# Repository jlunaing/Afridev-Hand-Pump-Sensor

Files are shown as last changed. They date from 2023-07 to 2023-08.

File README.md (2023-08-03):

# Monitoring System for the Afridev Hand Pump

## Overview

[Source code](src), [circuit schematic and board files](pcb), and [**technical report**](docs) of a proof-of-concept electronic system to monitor the status of the Afridev model of hand pumps.

<p align="middle">
   
</p>

<p align="middle">
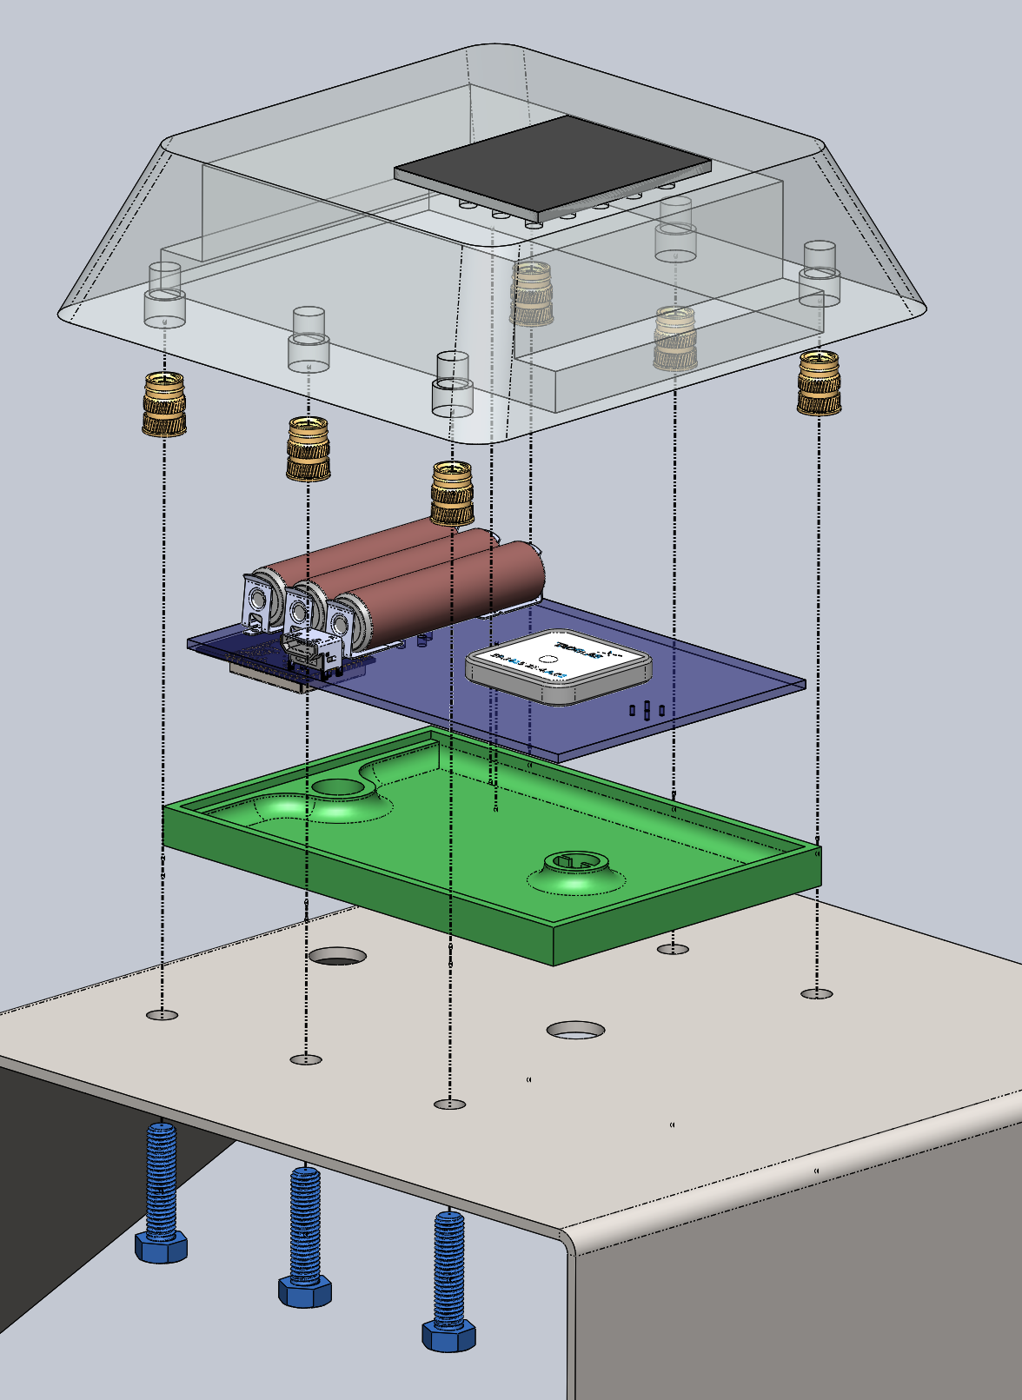
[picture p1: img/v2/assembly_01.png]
   
</p>

<p align="middle">
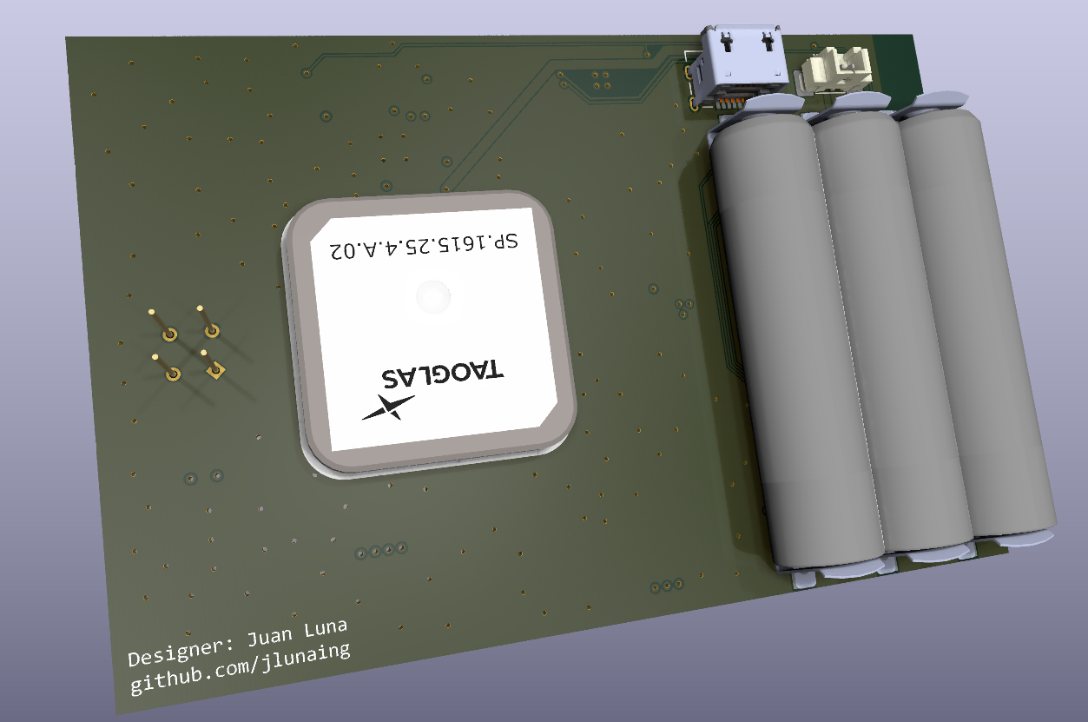
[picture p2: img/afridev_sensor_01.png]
Figure 3A
  
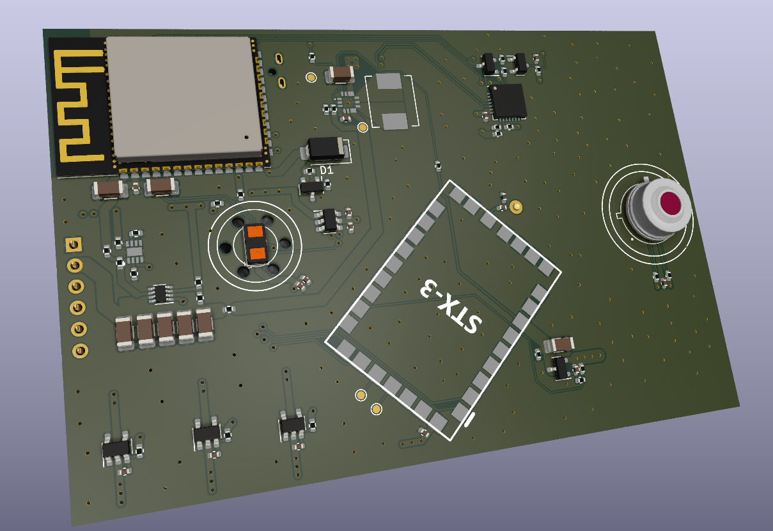
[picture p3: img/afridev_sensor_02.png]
Figure 3B
   
</p>

## Introduction

Different companies, non-profit organizations, and NGOs have implemented water projects in several regions of Africa. One of the most common projects are hand pumps for water wells. A challenge that is presented once these projects are concluded and used by the local residents are that there is no regular maintenance of these hand pumps due to communication difficulties with the local communities. For instance, in most of the Democratic Republic of the Congo (DRC), the lack of cellular signal and internet connection makes it more difficult for repair teams to know when the hand pumps need repair or maintenance. 

The objective of this project is to propose a system that can reduce the time between pump failure and repair by developing a reliable failure detection measuring system that will inform a user when a pump need attention from a repair team. The system will collect data on pump usage and water flow rate estimation to be accessed remotely.

The reduction in hand pump repair time would increase the consistency of well water available to people in the remote areas like the DRC.

## Technical Background

Currently, there are no commercially available options for well pump sensors with the capabilities to detect pump function, monitor water flow rate, and transmit data internationally. However, open-source systems of a similar nature have been developed by other organizations. A notable one is [Charity: Water](https://www.charitywater.org/), a non-profit serving several developing countries through community water projects and sanitation efforts. Their [sensors](https://www.charitywater.org/our-work/sensors)&mdash;which can be retrofitted onto the Afridev, Tapstand, and India Mark II hand pump models&mdash;are able to collect data on the quantity of water being pumped from a well. The gathered data is transmitted to the cloud weekly via cellular networks, where it is stored, processed, and made viewable by an application running on Amazon Web Services (AWS). The Afridev model appears to have been developed from 2016 to 2020 by Intelligent Product Solutions (IPS), while the India Mark II sensor was developed in 2021 by TwistThink over the course of at least a year.

Extensive documentation for the Afridev and India Mark II models of the sensor is available on [GitHub](https://github.com/charitywater/india-mark-ii-sensor). Charity: Water's third generation Afridev hand-pump sensor expands on its predecessors with the ability to gather GPS, temperature, and device performance information. A more recent model, the India Mark II sensor, adds to these capabilities with additional stroke and humidity sensors. It costs $250 to build and maintain for its battery-limited 10-year lifespan and can collect ten million data points over a 24-hour period. This data is continually analyzed through Charity: Water's AWS backend, where personalized emails are dispatched to monitoring teams daily. Design specifications for Charity: Water's sensors are available from open source and served as an initial reference for this design.

The Charity: Water sensors all use a similar strategy to measure water flow rate. During a pumping cycle, water is brought into a chamber where its depth is measured by a series of capacitive sensors. From this, the quantity per pump&mdash;and therefore average flow rate&mdash;can be accurately estimated. While functional, this method has a few weaknesses. The capacitive sensors are highly sensitive to environmental changes such as temperature variation and require frequent (multiple per hour) automated calibrations to maintain measurement accuracy. Moreover, the sensor has an upper limit on the amount of flow it can measure per pump&mdash;any output over the chamber volume cannot be measured. With this setup, Charity: Water claims a 20% tolerance for the calculated flow rate, which was improved to 5% by IPS. More information can be found [here](https://github.com/charitywater/afridev2-sensor/blob/master/software/architecture%20and%20analysis/charity%20water%20AfriDev%20sensor%20algorithm%20v.2.pdf). 

In addition to the common water sensing strategy, both sensors also feature a cellular module to communicate with Charity: Water's cloud infrastructure, GPS to provide positioning, and battery power of undisclosed capacity. It is claimed that the India Mark II sensor can remain operational for up to ten years. While cellular communication is available in some areas of the DRC, coverage is sparce outside of urban settlements. See the [network coverage maps](https://www.gsma.com/coverage/#88) for details. This makes the use of Global System for Mobile Communications (GSM) technology difficult to implement for the pump distribution in the DRC. Satellite communication is a more reliable alternative, with coverage in the DRC by telecommunications infrastructure providers such as Globalstar, Swarm, and Astrocast. For instance, [Globalstar's satellite networks](https://www.globalstar.com/en-us/products/iot/stx3) cover the entirety of the DRC, where this monitoring sensor can be implemented.

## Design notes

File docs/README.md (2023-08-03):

### Contents

1. [Design Development](#design-development)
2. [Overview of Solid Model](#overview-of-solid-model)
3. [Electronic Components Selection](#electronic-components-selection)
4. [System Integration and Assembly](#system-integration-and-assembly)
5. [Overview of Software](#overview-of-software)
6. [Manufacturing](#manufacturing)
7. [Further Development](#further-development)

## Design Development

For the initial decision and selection process, means of achieving each required function of the system were defined using a morphological chart (**Table 1**). This involved brainstorming ideas based on background research about technologies and known solutions.

<div align="center"><b>Table 1.</b> Morphological chart for design development.<br><br>

| Functions | Means |
|  :----: | ----- |
| Measure flow rate out of the hand pump | <p align="left">- Monitor internal capacitance<br>- Flow meter/sensor<br>- Water wheel </p>|
| Convert mechanical energy to electrical energy | <p align="left">- Inductor array<br> - Magnets and coil </p>|
| Translate electrical energy | <p align="left">- Convert analog to digital<br>- Memory to transmit package<br> - Convert to correct units </p>|
| Transmit data | <p align="left">- Satellite<br>- Cellular </p>|
| Conserve battery life | <p align="left">- Solar panel<br> - Capacitor array </p>|
| Protect from external environment | <p align="left">- Epoxy resin enclosure<br>- Sensor box inserted inside pump<br>- Polycarbonate housing </p>|

</div>

The functions and means were gathered in [decision matrices](decision_matrices.md) to compare methods based on different criteria. From these matrices, we selected the optimal method for achieving each function and brainstormed ways to combine these components. The different key components of our design include the power management, processing, system enclosure, pump functionality sensing, and wireless communication.

Regarding the system enclosure, an early design considered aluminum as a  suitable option based on durability, waterproofing, and environmental resistance to factors such as UV exposure. Upon further analysis and conceptual integration, we realized that aluminum would inhibit the ability of the system to transmit data. Furthermore, the thermal properties of aluminum could foster an internal temperature inside the enclosure that may not be ideal for component operations. High temperatures within the enclosure and pump could also facilitate evaporation of water inside the pump, resulting in condensation and potential damage within the circuitry. As such, the final version uses 3D-printed polycarbonate and epoxy seal to ensure that the electronics are both permanently protected and able to transmit data without an external antenna.

For power generation and storage, we paired a solar panel and lithium-ion batteries to harvest natural energy and store it within the battery. Power management is driven by the integration of low-power devices and using a sleep/idle mode on the system. This way, the limited power from solar energy can be preserved for longer. A modification from the initial design involved switching from the single 18650-sized battery to three small 10440 AAA-sized batteries connected in parallel to minimize the final package height.

To transmit data wirelessly, we determined satellite to be a feasible option in our region of operation within the DRC, due to the lack of cellular coverage in the Équateur Province. Initially, we selected SWARM as a satellite provider for their pricing and reliable coverage. However, their modem requires a large antenna to communicate with the satellite, which puts the functionality of the device at risk if the antenna were to be damaged or stolen. We aimed to find a new satellite device and provider that offered a small and subtle design that can be fully enclosed within the system. This necessitated a switch to a higher-frequency network that could be used with a smaller antenna. We settled on GlobalStar as a provider, which operates its network at a frequency of $1.6$ GHz. Their STX3 patch antennae integrates into the final, lower-profile design and can transmit data to the United States using satellite.

## Overview of Solid Model

**Figure 1-2** illustrates the final iteration of the system design. It features a printed-circuit board inside a polycarbonate housing. The system was designed with subtlety in mind, so it features a low-profile exterior that protects the electronics inside. The unit is securely fastened to the top panel of the Afridev hand pump with fasteners that are hidden from external view. At the bottom surface, the enclosure has dimensions of $90 \times 115$ mm and is attached to the top cover of the hand pump, directly over the axis of motion of the plunger, allowing downward clearance for both the time-of-flight and the infrared sensors.

<p align="center">
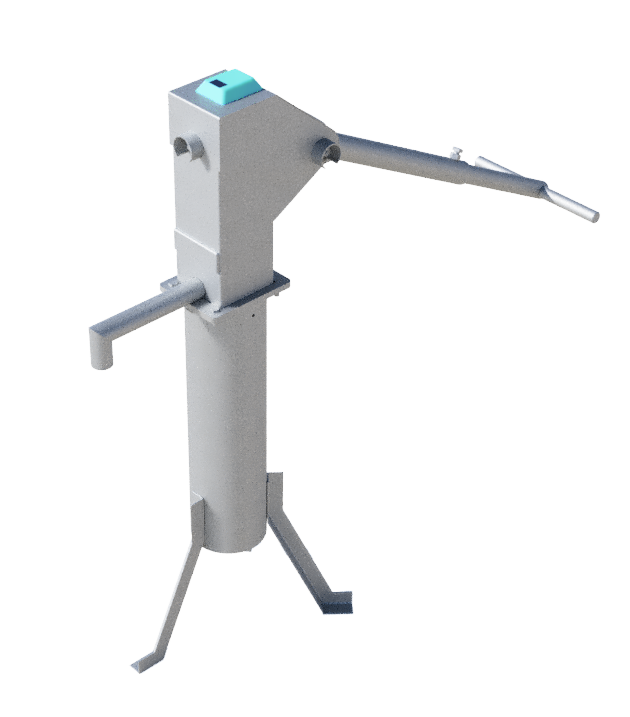
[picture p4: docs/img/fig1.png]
   
</p>

<p align="center"><b>Figure 1.</b> Monitoring system installed on top of the Afridev hand pump.</p>

<p align="center">
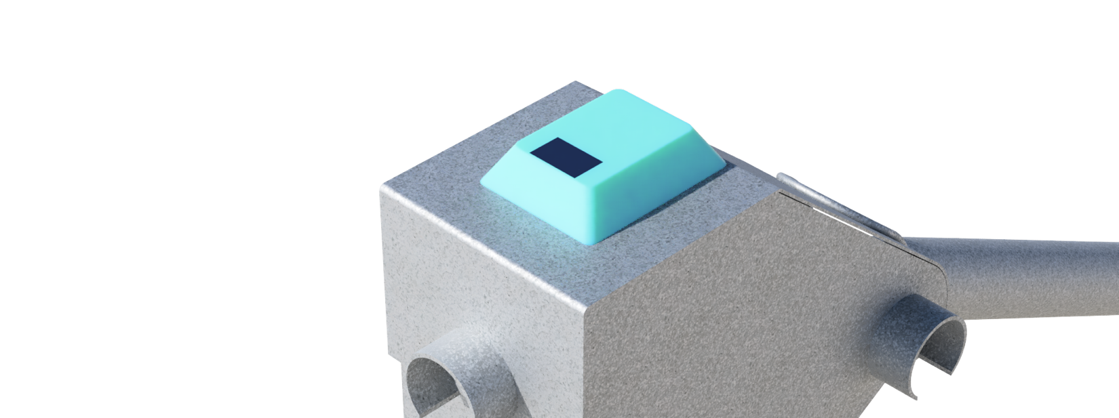
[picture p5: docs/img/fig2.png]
   
</p>

<p align="center"><b>Figure 2.</b> Close-up view of monitoring system.</p>

A detailed solid of the polycarbonate enclosure can be found in the [hardware](hardware) folder, where version [v2](hardware/v2) corresponds to the latest design. The mechanical design of the housing features walls at $60\degree$ angles to dissuade removal of the sensor. The electrical system consists of batteries, a solar cell, charge controller, two sensors, a satellite modem, and a microcontroller. These components, as described in the following sections, are integrated into a PCB which is situated between the bottom and top housing. An exploded and collapsed view of the housing and the PCB is shown below (**Figure 3-4**). Detailed engineering drawings and the detailed electrical circuit schematic can be found in the [Drawings](hardware/v2/Drawings) and [PCB](pcb) folders. The software system that the design will use to process the data is described in the software development plan in the [Product Realization](#product-realization) section.

<p align="middle">
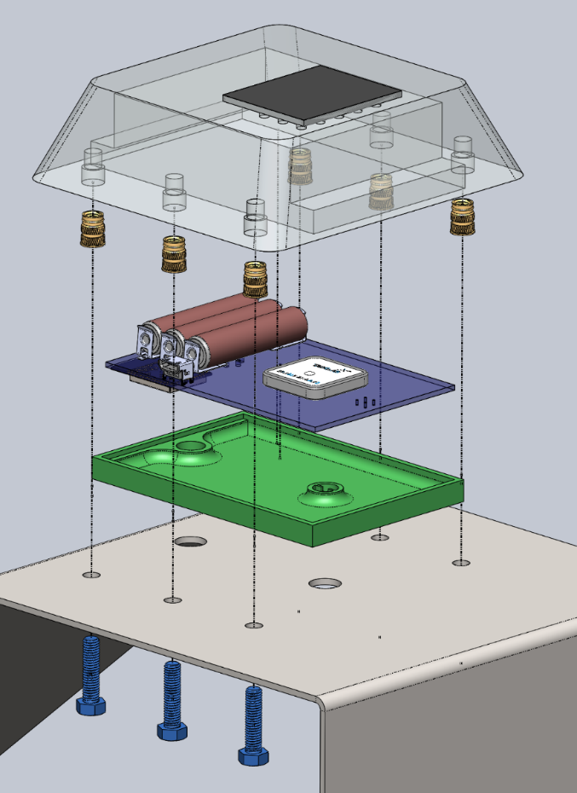
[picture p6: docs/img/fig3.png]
   
</p>

<p align="center"><b>Figure 3.</b> Exploded view of monitoring system. Colors shown for visual purposes.</p><br>

<p align="center">
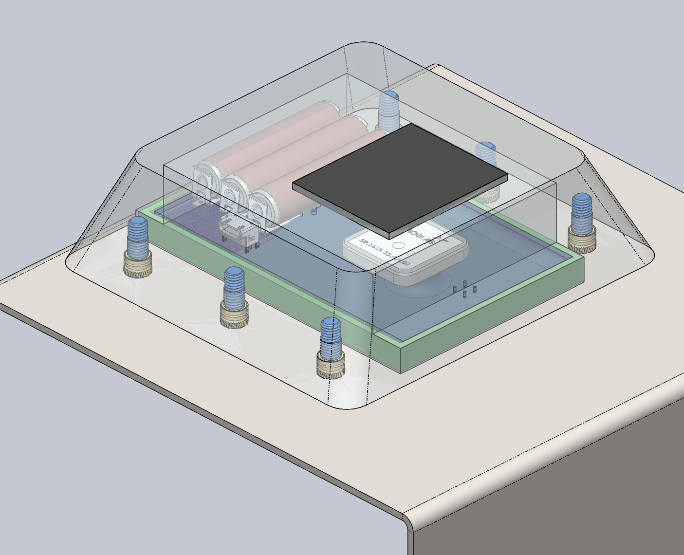
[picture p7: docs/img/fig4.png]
   
</p>

<p align="center"><b>Figure 4.</b> "Collapsed" exploded view of monitoring system</p>

## Electronic Components Selection

The components can be selected based on constraints and factors including cost, performance metrics, compatibility and others described earlier in the design development section. To provide power to the sensor system, three 10440 AAA rechargeable lithium-ion phosphate batteries, also known as LiFePO4 batteries, were selected. Compared to traditional alkaline AAA batteries, 10440 LiFePO4 batteries have a higher voltage, energy density, and are rechargeable so they can provide more power and last longer. They also have a more stable chemistry than other lithium-ion alternatives, lasting up to 10 years. Connected in parallel, these batteries will supply $3.2$ V of power with a combined capacity of $1200$ mAh. The LiFePO4 is a readily available battery, often used in solar garden lights and similar home applications. Since they will be connected in parallel, charging is balanced between the two batteries. 

The design also incorporates the [SM141K06L](https://www.digikey.com/en/products/detail/anysolar-ltd/SM940K12L/9990451) monocrystalline solar cell, which will recharge the batteries from solar energy. This specific cell provides a $4.15$-V nominal output with 183-mW peak power. It comes pre-sealed and has a size of $35\times22$ mm, allowing for ease of integration. To incorporate the solar cell and batteries, we use a shunt charger. This is the simplest type of charger and can be used in this application because the capacity of the batteries far outclasses the maximum output of the solar cell. The solar cell is directly connected to the batteries, and a shunt circuit limits voltage to the battery’s max&mdash;about $3.6$ V. When the batteries are full, additional power generated by the solar cell is simply wasted as heat through the shunt to keep the battery voltage below its max. The maximum power point (MPP) of the solar cell is specifically selected so that it is near the target voltage of the battery, ensuring efficient power extraction. When charging at around $3.5$ V, the panel will sit at about $3.7$ V after a reverse-bias diode, which is near enough the MPP for efficient operation.

To ensure that the handpump system is working, two sensors are responsible for measurements&mdash;specifically, detecting physical pumping action and the presence of water. The [VL53L4CD](https://www.digikey.com/en/products/detail/adafruit-industries-llc/5425/16499347) time-of-flight sensor from ST Microelectronics measures the position of the pump plunger as it moves vertically during pumping. From this displacement and the known cross-sectional area of the plunger, water outflow can be estimated. The sensor includes some useful features such as adjustable distance threshold interrupts that can be used to optimize the power draw of the microcontroller. It also features an accuracy of about $5$ mm. This component runs on $3.3$ V, with a current draw of $19$ mA during active mode and $5$ $\mu$A in idle mode.

Likewise, to detect whether water is indeed flowing when pumping action occurs, we selected the [MLX90614](https://www.digikey.com/en/products/detail/melexis-technologies-nv/MLX90614ESF-BAA-000-SP/5414793) digital infrared temperature sensor from Melexis. By measuring the temperature of a region of the pump that becomes flooded when water is flowing, a temperature drop can be used to directly check that water is present. Its measurement resolution, accuracy, and wide range make it suitable for our purposes. It requires a power supply in the range $2.6$-$3.6$ V to measure temperatures from -$40$ to $85\degree$C.

To transmit data back to CLEAN, we chose the [STX3](https://www.globalstar.com/en-us/products/iot/stx3) satellite modem from Globalstar. It relies on a low-profile, $20\times20$-mm patch antenna that is mounted directly to the PCB together with a surrounding $60\times60$-mm ground plane to function. Globalstar's network covers the entirety of the DRC and operates at an L-band of $1.6$ GHz. At the time of writing this report, each STX3 Modem comes at an initial cost of $60, with a subscription of $16 per month for data transmission.

To interface with the sensor and satellite module as well as control the overall behavior of the electronic system, we chose the ESP32-S2 microcontroller (MCU). The ESP32 series of microcontrollers is highly integrated, ubiquitous, and features built-in Wi-Fi. The [S2 variant](https://www.espressif.com/sites/default/files/documentation/esp32-s2_technical_reference_manual_en.pdf#sysmem) also features an ultra-low-power RISC-V co-processor which can be used to run arbitrary code while the main, power "hungry", MCU is in deep-sleep. This co-processor has low power consumption at $627$ $\mu$W and&mdash;important for this application&mdash;has access to the I2C peripheral. This enables it to communicate with the various sensors without booting the main MCU. The co-processor also has access to $8$ kB of SRAM, which is sufficient for the outlined requirements. The primary processor has $1$ MB of flash and $320$ kB of SRAM [22]. The primary processor has access to additional UART peripherals, which are used to communicate with the satellite transceiver. This system uses the C programming language for developing the code. It integrates into our compact design with dimensions of 18x25mm [16]. The extremely rich feature-set of the ESP32-S2 also keeps doors open to additional features like a smartphone-enabled setup.

The [MAX77827](https://www.mouser.com/new/analog-devices/maxim-max77827-switch-buckboost-converter/) buck-boost converter IC was selected to regulate the main $3.3$-V rail at an efficiency of $96$ %. It accepts input voltages in the range of $2.3$-$5.5$ V and can output a steady $3.3$ V, regardless of whether the input voltage is above or below the target. This is important for functionality, as during satellite transmission, peak current draws may cause battery voltages to dip below $3.3$ V, making a standard step-down only converter inadequate.

To monitor battery voltage, the system uses the [MCP3425A0T](https://www.digikey.com/en/products/detail/microchip-technology/MCP3425A0T-E-CH/1827893) ADC. This component supports I2C serial interface and runs within the range of power supplied by the previously mentioned buck converter. It has up to $16$-bit resolution in a SOT-23-6 package and can use its internal $2$-V reference to sense the entire battery range without needing a voltage divider. An external ADC is used instead of the ESP32’s built-in ADC to manage quiescent current. The ESP32’s ADC is notoriously poor and has a relatively low impedance&mdash;it will waste power if used.

To preserve the Lithium-ion batteries, the [XB8358D0](https://datasheet.lcsc.com/lcsc/1809131533_XySemi-XB8358D0_C80218.pdf) has been integrated. This battery management IC is contained in a small SOT23-5 package and runs on low current, switching between operation mode ($2.8$ $\mu$A) and power-down mode ($1.5$ $\mu$A). This IC will extend battery life by protecting against overcharging, over discharging, overcurrent, load short circuiting, and reverse polarity. While not strictly necessary if the batteries are never replaced, it is included under the assumption that batteries should be serviceable by laypeople.

Additional components, included only for testing and validation on the prototype, include the CP2102 USB-serial converter, the BQ25170DSGR Li-ion charger, and the LM66200DRLR power switch. These components should not be populated for production versions of the device.

## System Integration and Assembly
 
The PCB is mounted onto the bottom part of the housing, where an electrical potting compound is used to permanently the bottom side of the PCB. The two holes surrounding the time-of-flight and infrared sensors are designed to prevent the potting epoxy from leaking onto the sensors and causing issues (**Figure 5**). 

[Epoxy Seal 9000](https://www.theepoxyresinstore.com/products/epoxyseal-9000-2-to-1-electronic-grade-potting-epoxy-resin-48oz-kit) has high temperature and impact resistance and keeps moisture out of the enclosure. This product is RoHS compliant and can be purchased online for $0.08 per fluid ounce, at the time of writing this report. Potting the important components secures the design against component theft and water damage.

The solar panel is mounted to the top part of the housing, with the perforations beneath it designed to allow epoxy to hold it in place effectively (**Figure 6**). This part of the housing has six holes in which metal heat-set inserts can be placed for later attachment to the pump.

<p align="center">
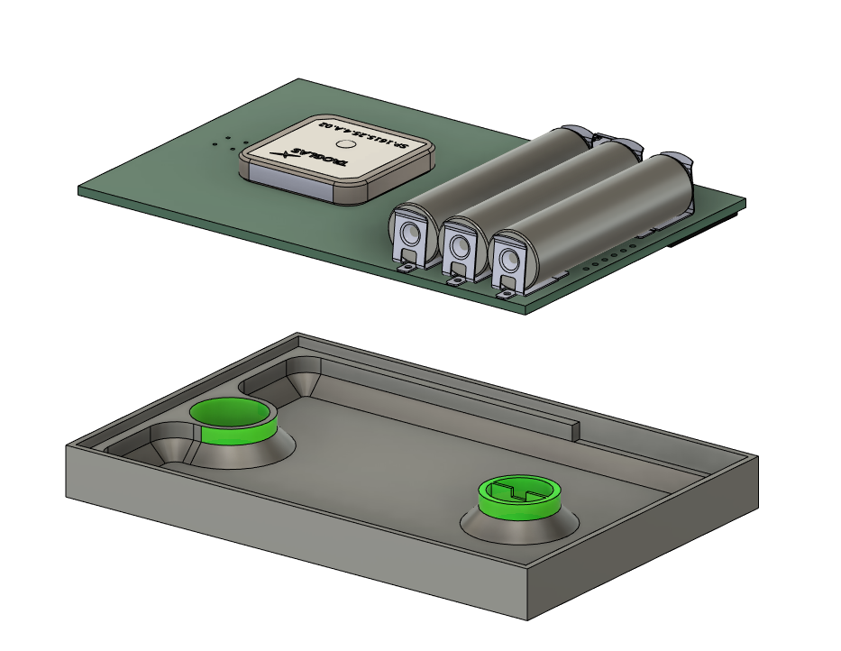
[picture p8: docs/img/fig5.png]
   
</p>

<p align="center"><b>Figure 5.</b> The PCB and associated part of the enclosure, with sensor holes highlighted.</p><br>

<p align="center">
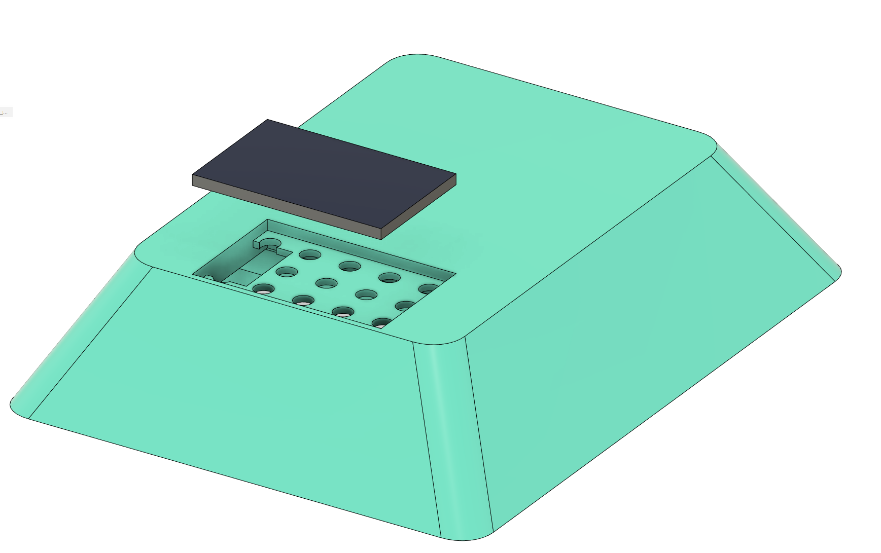
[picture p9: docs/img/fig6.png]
   
</p>

<p align="center"><b>Figure 6.</b> The solar panel and its associated perforations.</p>

To assemble the system onto the hand pump, we first drill six holes through the top cover of the hand pump according to the [drawings](hardware/v2/Drawings). These holes match the position of the heat-set inserts on the top part of the enclosure.

Then, the joint assembly of the bottom enclosure with the PCB are placed on top of the pump with its edges inside the perimeter created by the position of the holes on the cover plate of the pump. The solar panel, sealed on top of the top enclosure is connected through its terminals to the PCB. The top enclosure is lowered and mates with the bottom enclosure. Finally, the this assembly is fastened to the cover of the hand pump using M3 screws and the heat-set inserts already on the enclosure. Epoxy seal was not used for the prototype developed to maintain accessibility and viewability of the design.

Combined with slightly undersized holes, these heat-set inserts produce a locking effect like nylon locknuts. The trade-off for the added security from potting and locking screws is that only the replacement of the solar panel and batteries is possible. Therefore, extensive testing should be completed to ensure longevity of each component and the whole system, which would be deployed as a single unit that requires replacement approximately every 10 years. 

## Overview of Software

The software required to create a functioning system needs to be able to perform data collection, translation, and transmission, as well as transitioning a system between idle and active mode. The software is programmed and processed on a microcontroller unit (MCU) that acts as the central controller for the entire system. The finite state diagram for the software is shown in **Figure 7**.

<p align="center">
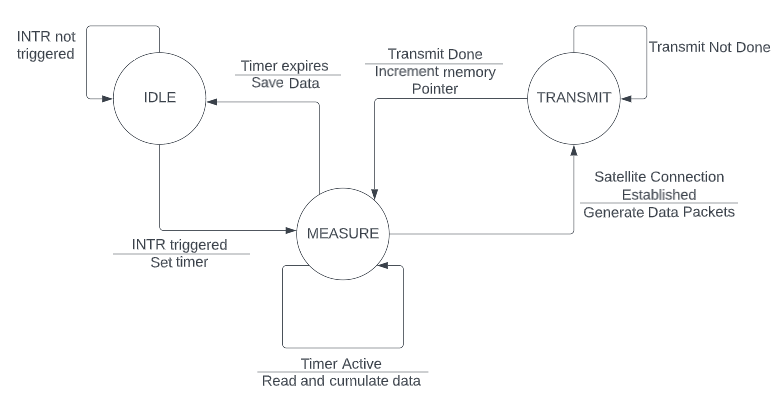
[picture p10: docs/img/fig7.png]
   
</p>

<p align="center"><b>Figure 7.</b> Finite state machine driving the microcontroller unit.</p>

For data collection, the temperature (IR) and distance (ToF) sensor work in tandem to detect if the pump is working. To begin data collection, the ToF sensor is first used to detect if the handle is being pumped. This communicates with the MCU using the I2C protocol and provides accurate measurements. When the sensor reads that the pump is pulled up, the sensor triggers an interrupt (INTR in diagram) in the MCU to come out of [standby mode](https://www.st.com/resource/en/user_manual/um2923-a-guide-to-using-the-vl53l4cx-timeofflight-sensor-with-extended-distance-measurement-stmicroelectronics.pdf). The MCU then turns on the IR sensor, which takes measurements on the ambient and object temperature. The target of interest for the IR sensor is the bottom of the tank where water starts collecting, and the measured data is the temperature difference caused by the presence of water within the tank of the hand pump, relative to the temperature of the tank when no water is present, as described earlier. The MCU makes use of a timer, that is set when the interrupt is triggered, to minimize the data collection when the pump is not being used. 

For data translation, the system must be able to translate measured data values into volumetric measurements of water being pumped. The MCU uses the displacement of the pump handle mechanism to estimate the volume of water displaced by the plunger. This relationship can be determined empirically from testing with the Afridev pump. The IR sensor determines if water is present at the time of pumping. These measurements are calculated and translated to the number of liters output by the pump and detect if the pump has failed or not.

For data transmission, the MCU uses satellite to send the data internationally. The MCU prepares the data packets to send, which may include the pump number, failure status, a checksum, and number of liters pumped over the course of a day. The pump number is a numerical representation of a pump station that can be mapped to the physical location of the pump. The failure status displays if a pump has failed or is still active. The checksum is a calculated value that is sent with the data packet to be checked at the receiving end, to ensure that data has not been corrupted during transmission. The number of liters can be stored and displayed within an  external database.  

## Manufacturing

In regard to the PCB, most components were pre-populated on the board from the PCB manufacturer's assembly service. This is convenient as it saves time and money&mdash;the components they have open for selection are often orders of magnitude cheaper than what can be found on popular supplier sites. Components that could not be found in their available library for assembly were ordered from Mouser and Digikey then soldered by hand. The demonstration enclosure was printed on a group member’s 3D printer out of PETG. 

<p align="middle">
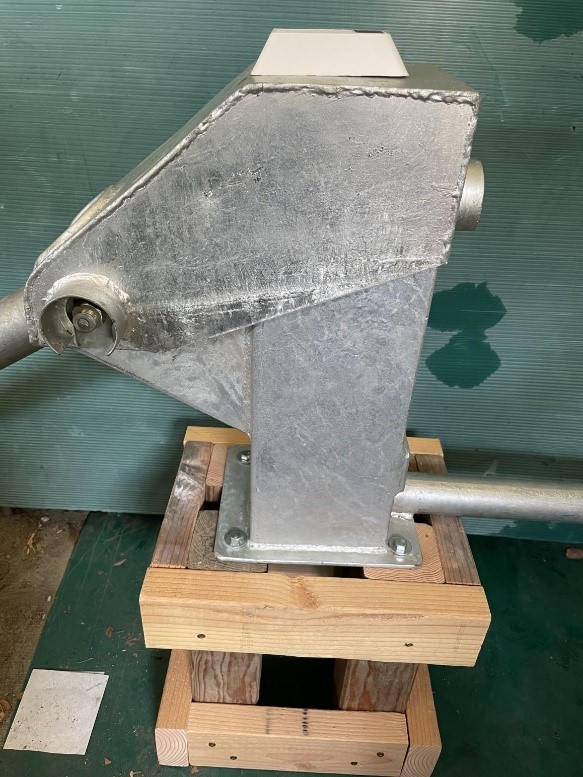
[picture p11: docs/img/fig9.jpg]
  
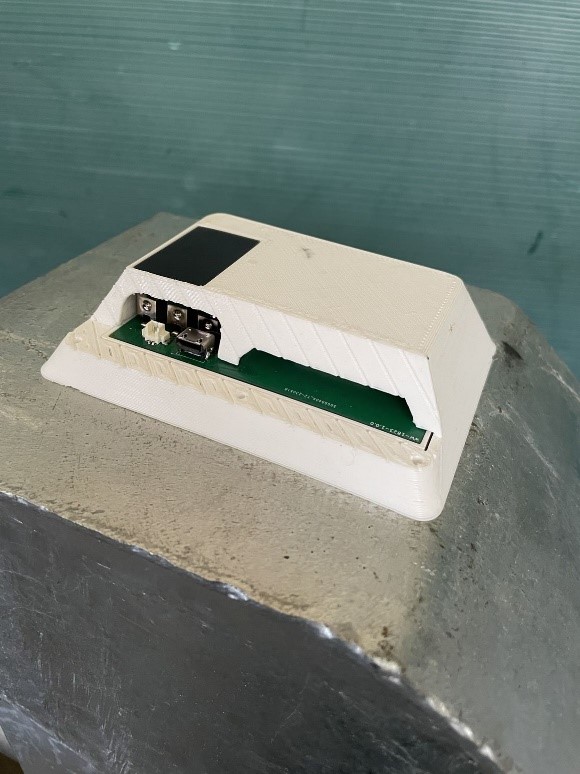
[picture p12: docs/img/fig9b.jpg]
   
</p>

<p align="center"><b>Figure 9.</b> Model Afridev hand pump on stand (left) and open sensor prototype on pump (right).</p>

## Further Development

These are some recommendations for further developing this project. There are areas where costs can be potentially cut, if desired. In particular, the MLX90614 temperature sensor&mdash; which represents a significant cost&mdash;can likely be replaced with a standard Passive Infrared (PIR) element like those from Zilog. This is possible because it only needs to effectively detect the temperature difference caused by flowing water, not the temperature itself. Additionally, the satellite transceiver should, once coverage expands to the USA in 2024, likely be replaced with the Astronode series of transceivers from Astrocast instead of the chosen Globalstar counterparts. These modules are both more diverse in features and cheaper to buy and operate than the Globalstar offering integrated into the prototype.

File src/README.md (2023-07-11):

This is the firmware base for the remote well pump monitoring system, designed 
to run on an ESP32-S2 with peripherals VL53L4CD Time-of-Flight sensor and 
MLX90614 IR temperature sensor.

The source files in this directory are intended for PlatformIO Test Runner 
and project tests. 

Unit Testing is a software testing method by which individual 
units of source code, sets of one or more MCU program modules together with associated
control data, usage procedures, and operating procedures, are tested to
determine whether they are fit for use. Unit testing finds problems early
in the development cycle.

More information about PlatformIO Unit Testing can be found [here](https://docs.platformio.org/en/latest/advanced/unit-testing/index.html).

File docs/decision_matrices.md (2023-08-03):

## Decision matrices

The required functions of the system and the various ideas for the means to accomplish those functions were gathered in decision matrices. The required functions are measuring water flow rate, measuring mechanical motion due to pumping action, protect system with an enclosure, transmit data wirelessly, generate energy, and conserve battery life. For each function, we constructed a decision matrix to compare methods to accomplish the function based on different criteria and weights.

The decision matrices used to generate the conceptual design are shown below (**Figure 1-6**).

<p align="center">
   
</p>

<p><center><b>Figure 1.</b> Decision matrix for measuring flow rate.</center></p>

<p align="center">
   
</p>

<p><center><b>Figure 2.</b> Decision matrix for measuring pumping action.</center></p>

<p align="center">
   
</p>

<p><center><b>Figure 3.</b> Decision matrix for selecting enclosure material.</center></p>

<p align="center">
   
</p>

<p><center><b>Figure 4.</b> Decision matrix for transmitting data.</center></p>

<p align="center">
   
</p>

<p><center><b>Figure 5.</b> Decision matrix for energy generation.</center></p>

<p align="center">
   
</p>

<p><center><b>Figure 6.</b> Decision matrix for conserving battery life.</center></p>

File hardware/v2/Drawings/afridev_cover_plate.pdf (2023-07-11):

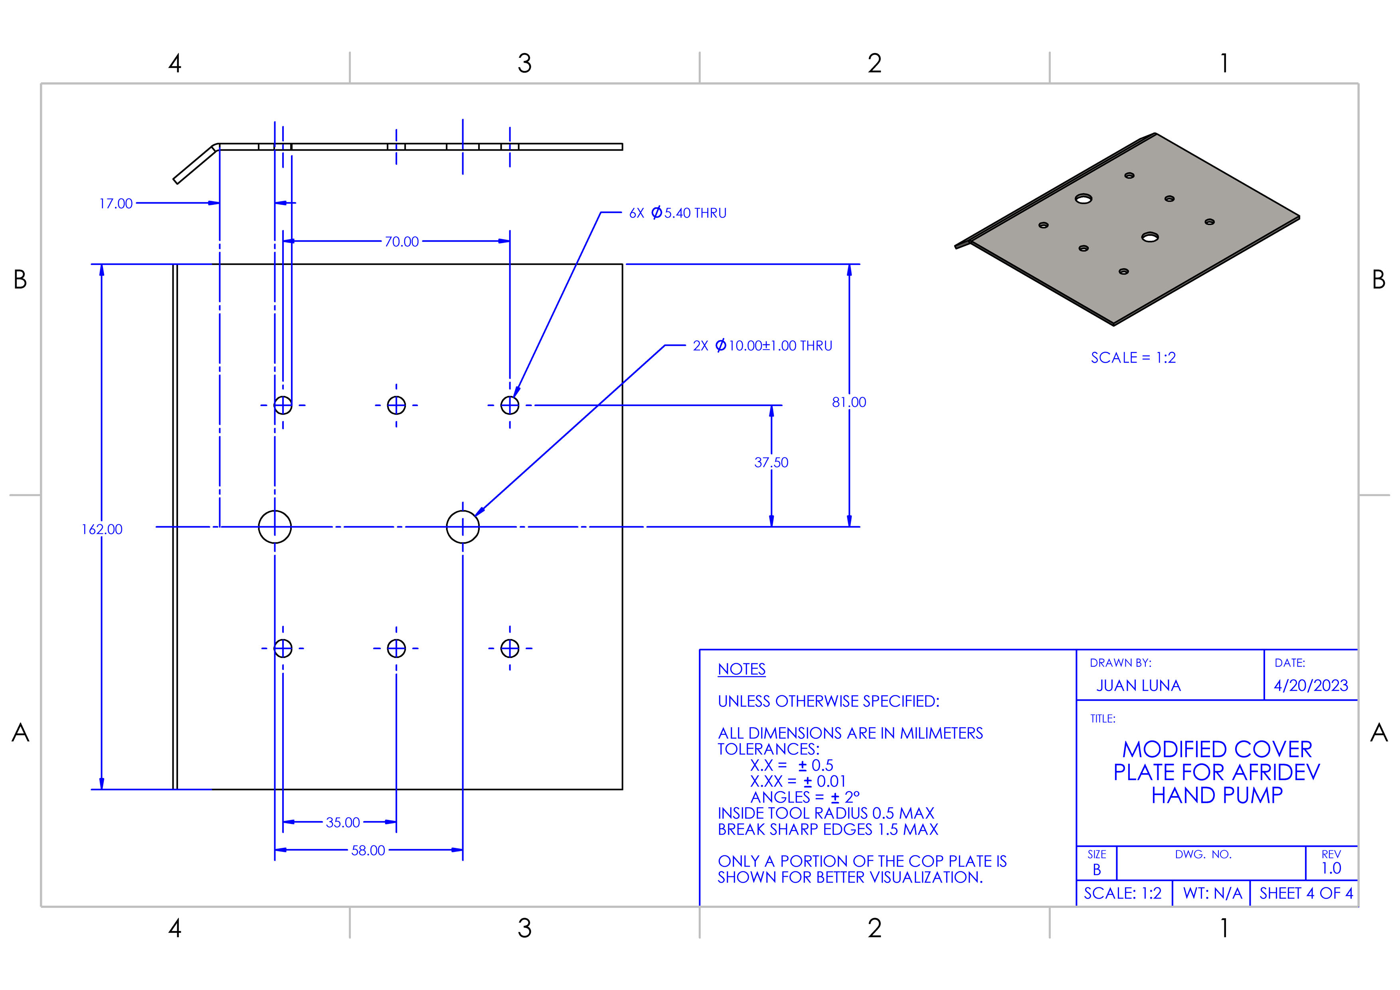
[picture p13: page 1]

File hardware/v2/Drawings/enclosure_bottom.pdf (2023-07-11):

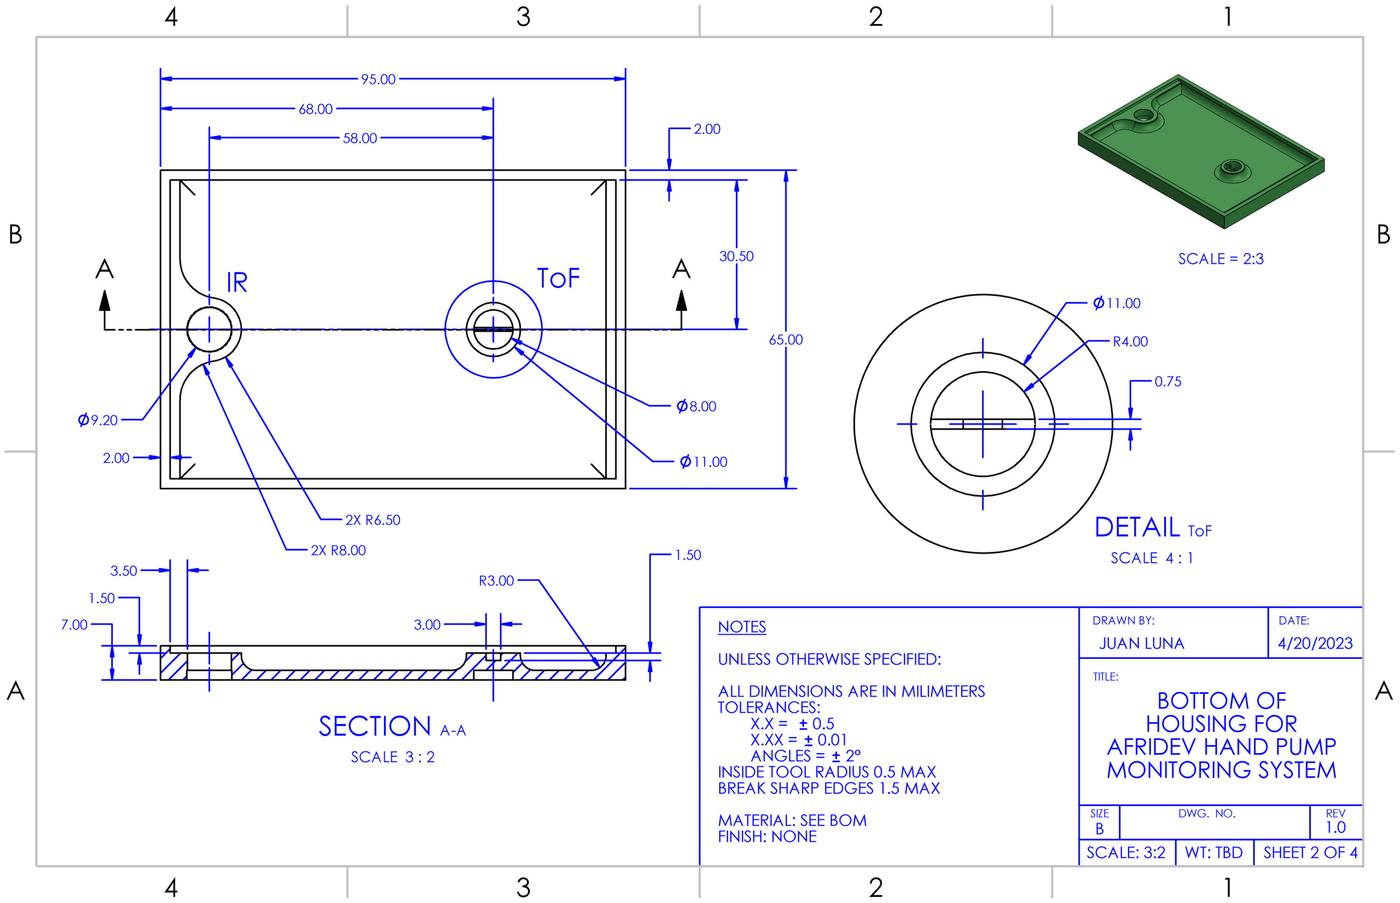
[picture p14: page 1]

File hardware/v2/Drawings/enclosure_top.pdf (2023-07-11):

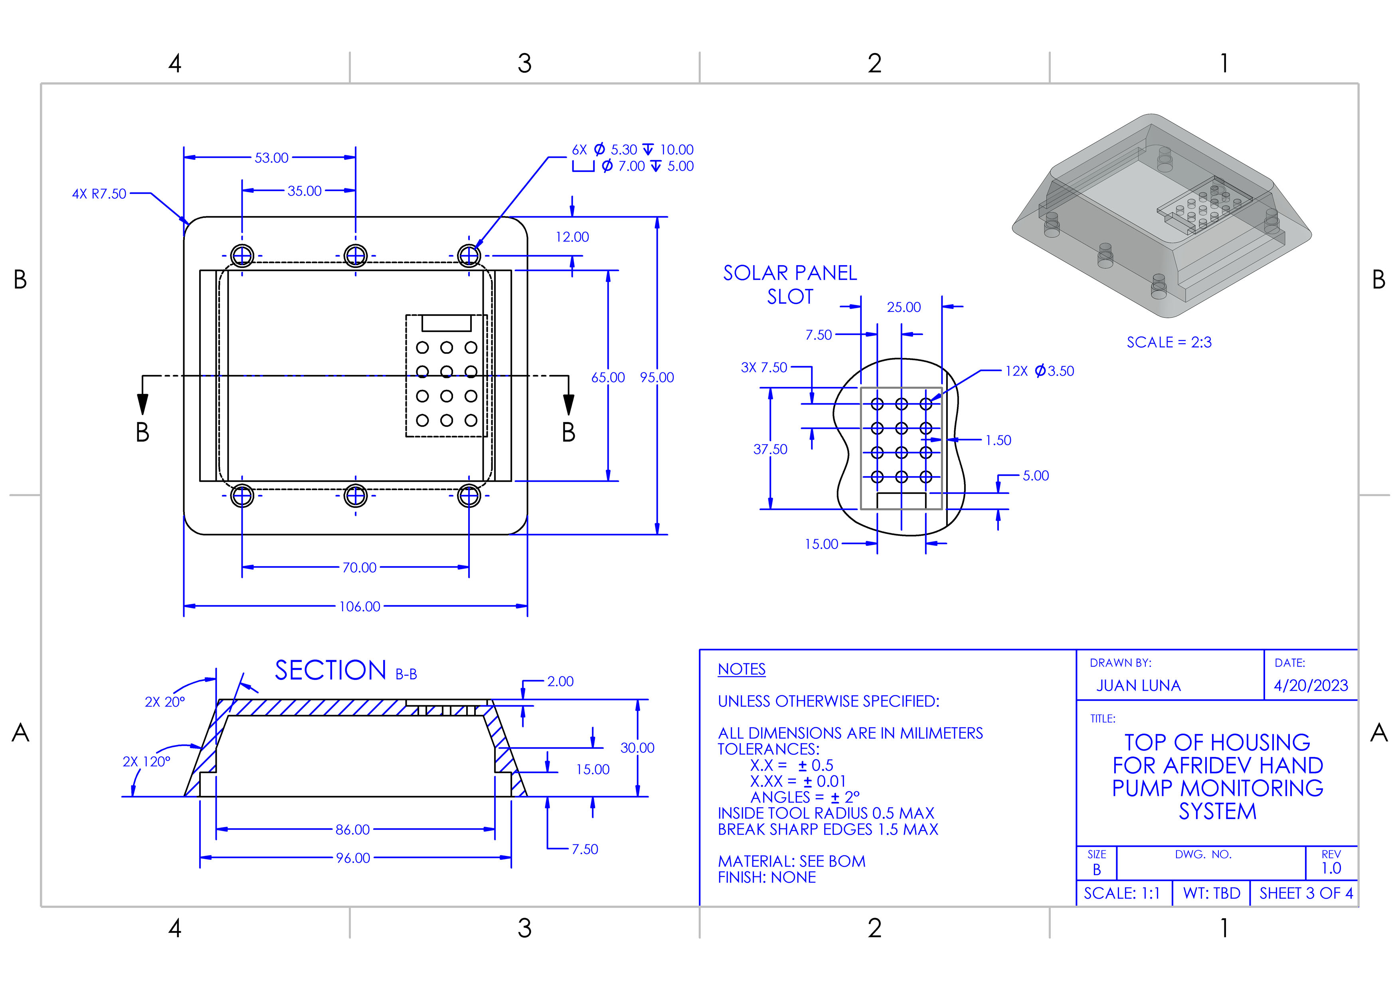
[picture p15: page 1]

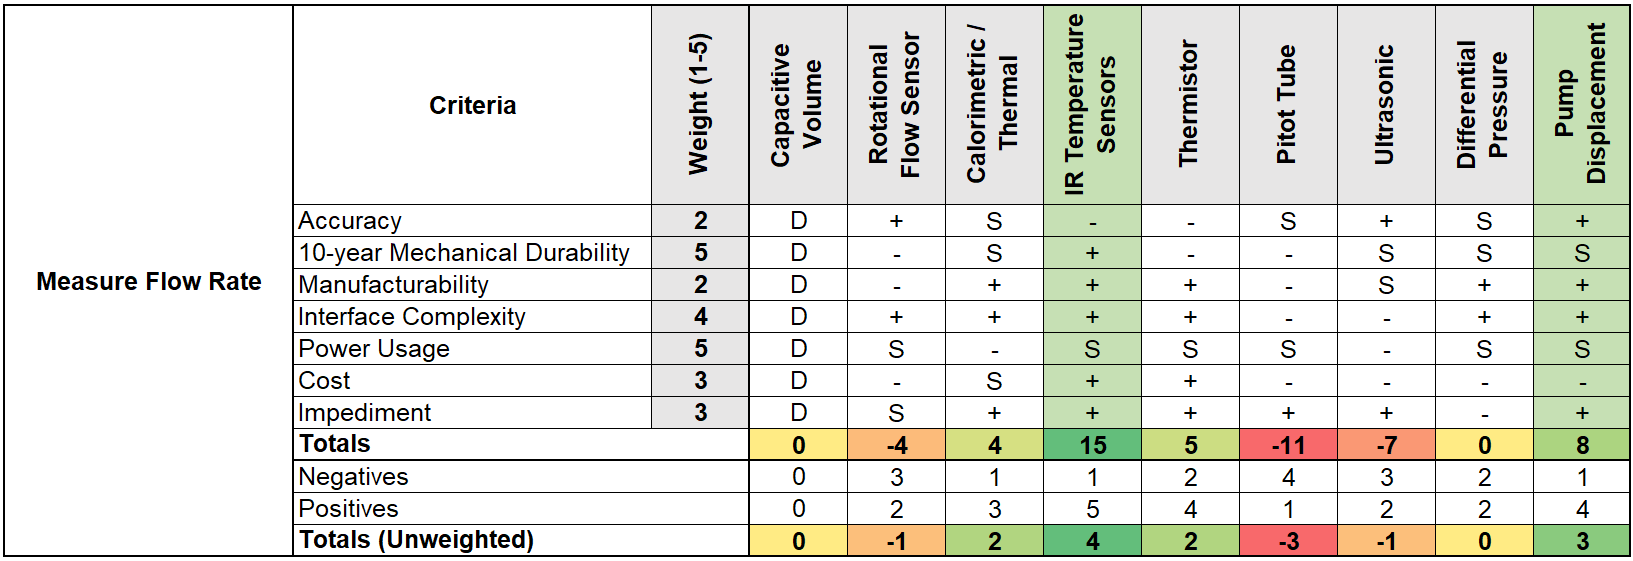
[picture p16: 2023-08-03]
docs/img/dm_flowrate.png

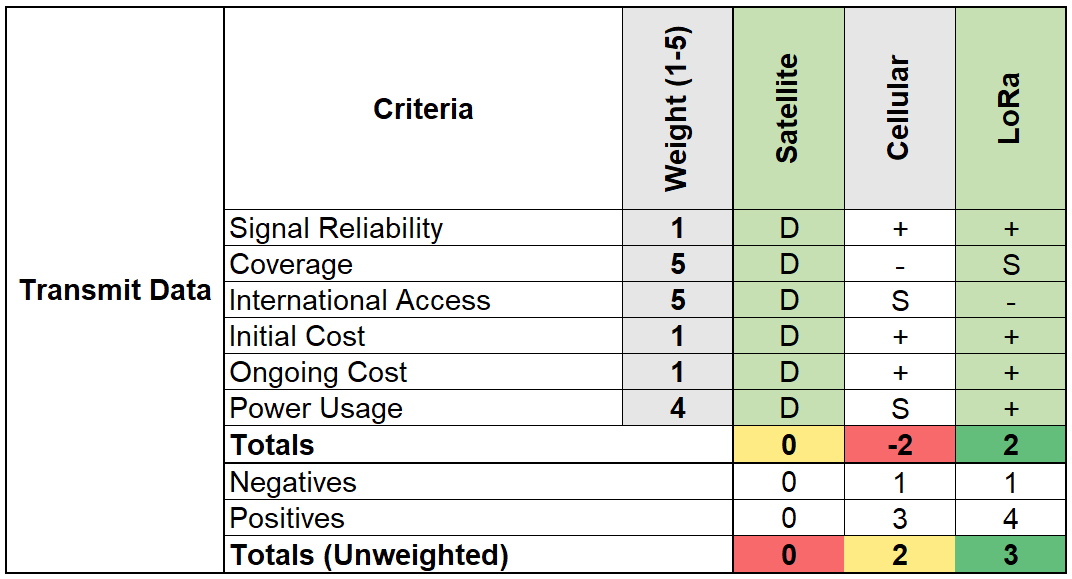
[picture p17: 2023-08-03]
docs/img/dm_transmission.png

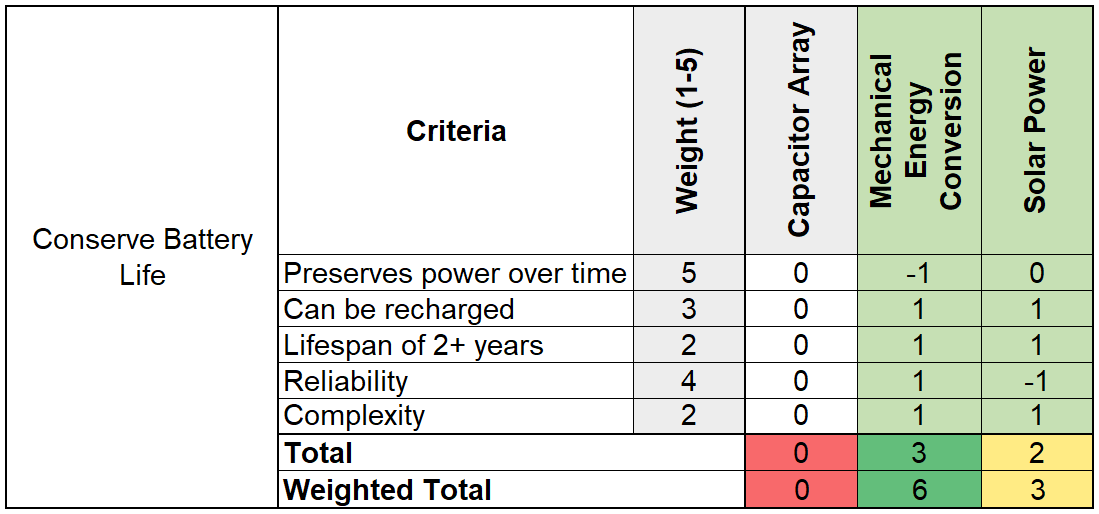
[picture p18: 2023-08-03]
docs/img/dm_conserve_battery.png

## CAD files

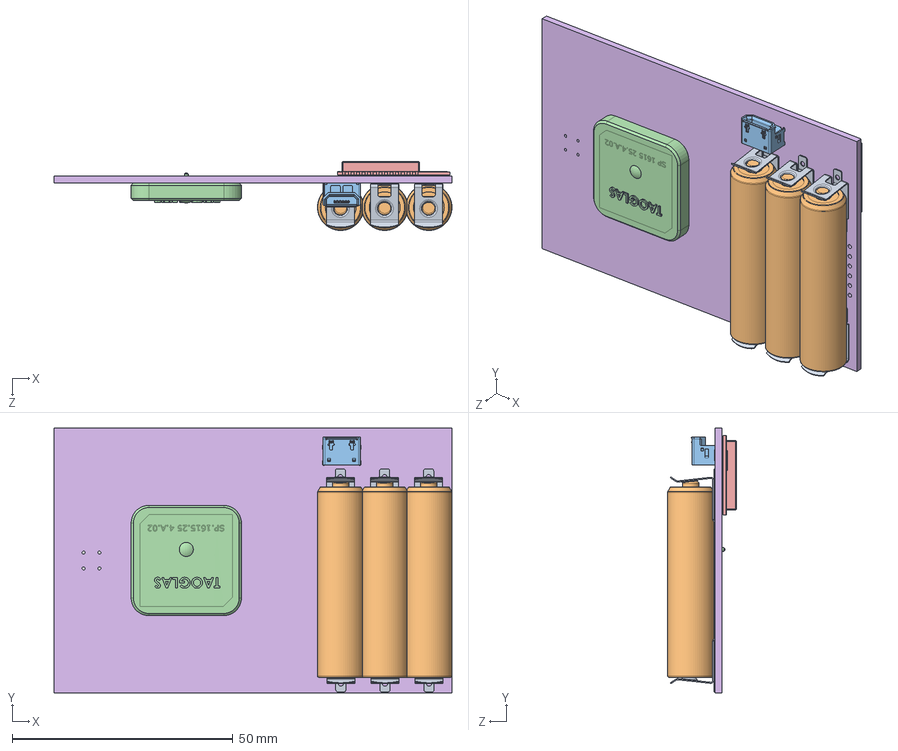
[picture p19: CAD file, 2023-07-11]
hardware/v2/board_assembly.SLDASM
90.2 x 60.0 x 15.6 mm
battery_terminal_01 x 6
battery_AAA x 3
micro_b_usb_connector
satellite_module
microcontroller
pcb

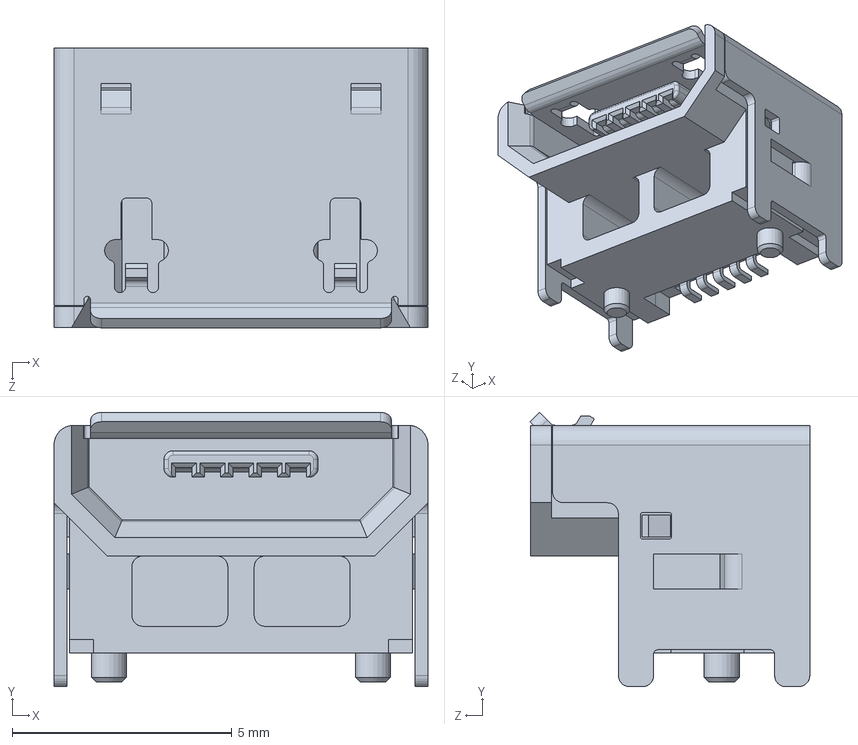
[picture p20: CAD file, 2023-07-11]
hardware/v2/GMCB05801124EU.SLDASM
8.50 x 6.23 x 6.36 mm

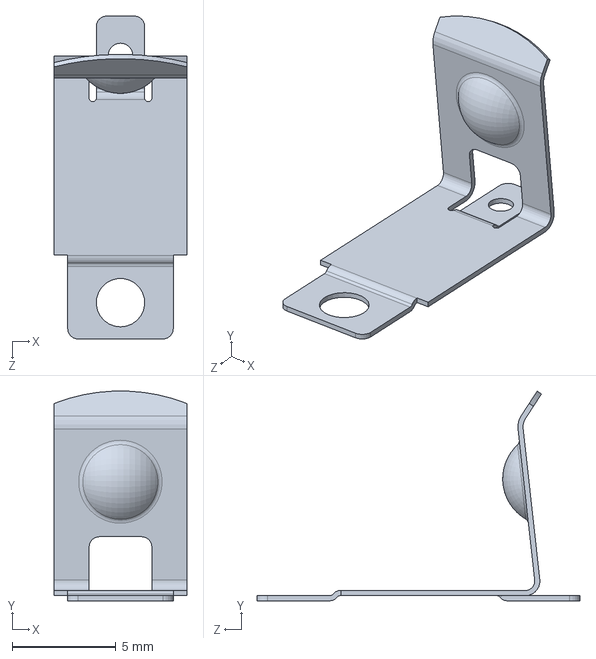
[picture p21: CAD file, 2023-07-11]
hardware/v2/bat-clip-56.SLDASM
6.40 x 10.1 x 15.6 mm

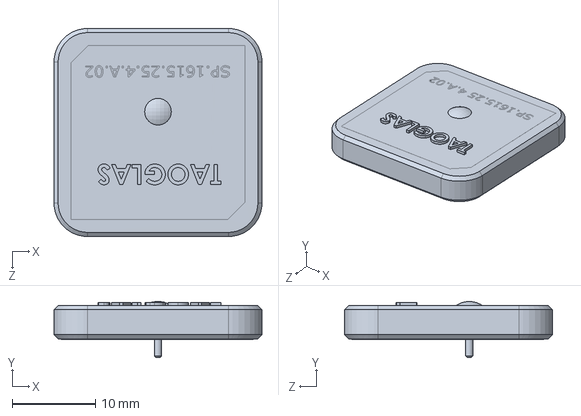
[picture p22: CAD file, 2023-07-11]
hardware/v2/SP-1615-25-4A-02.SLDASM
25.0 x 6.74 x 25.0 mm

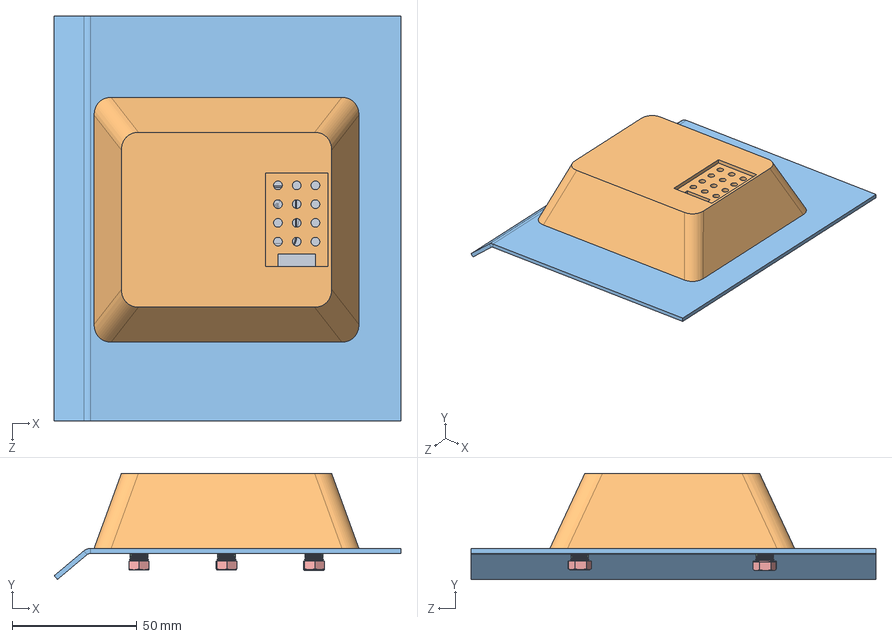
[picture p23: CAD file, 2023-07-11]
hardware/v2/enclosure_assembly.SLDASM
138.6 x 42.4 x 162.0 mm
enclosure_bottom
enclosure_top
afridev_C2037_cover_plate
97163A155_tapered_heat_set_insert_for_plastic x 6
91287A125_18-8_stainless_steel_hex_head_screw x 6

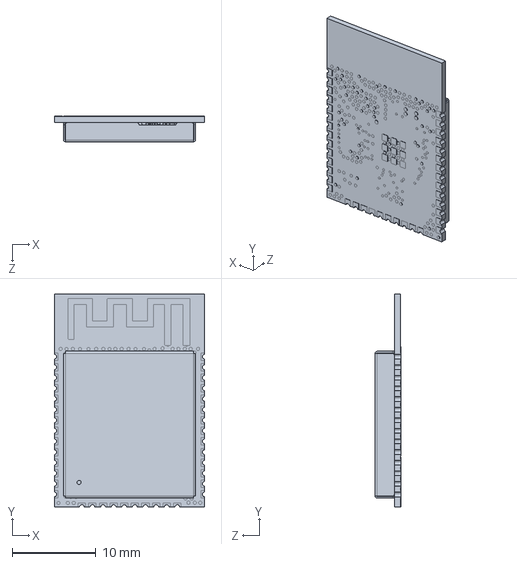
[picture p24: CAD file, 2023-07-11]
hardware/v2/ESP32-WROOM-32E.SLDASM
18.0 x 25.5 x 3.10 mm

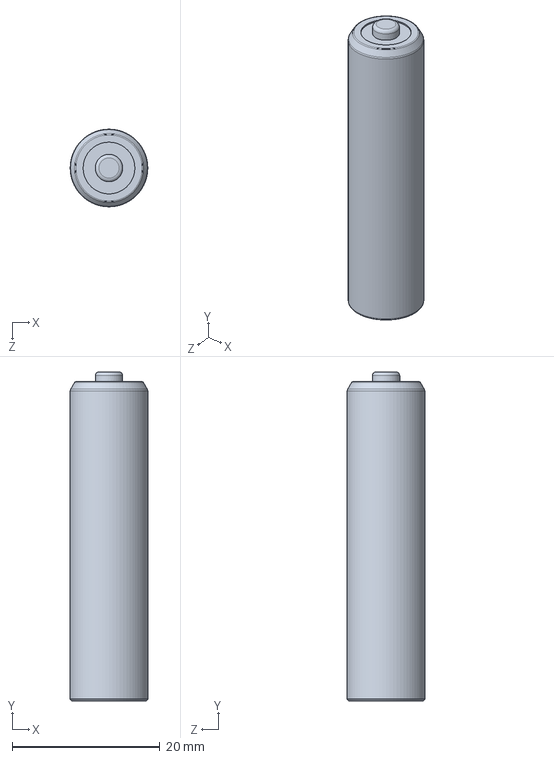
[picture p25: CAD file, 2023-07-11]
hardware/v2/bat-AAA-LR03.SLDASM
10.5 x 44.5 x 10.5 mm

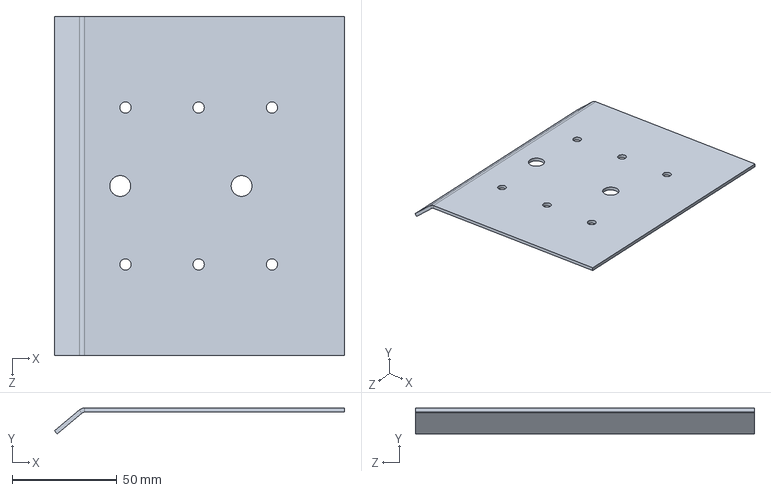
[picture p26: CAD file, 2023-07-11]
hardware/v2/afridev_C2037_cover_plate.SLDPRT
138.6 x 12.4 x 162.0 mm

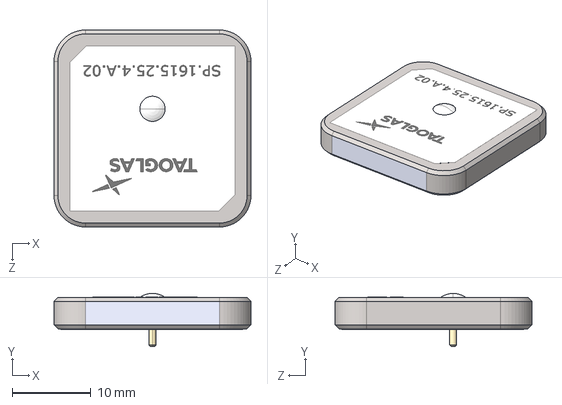
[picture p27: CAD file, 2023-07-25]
pcb/3d_models/SP.1615.25.4.A.02.STEP
25.0 x 6.75 x 25.0 mm

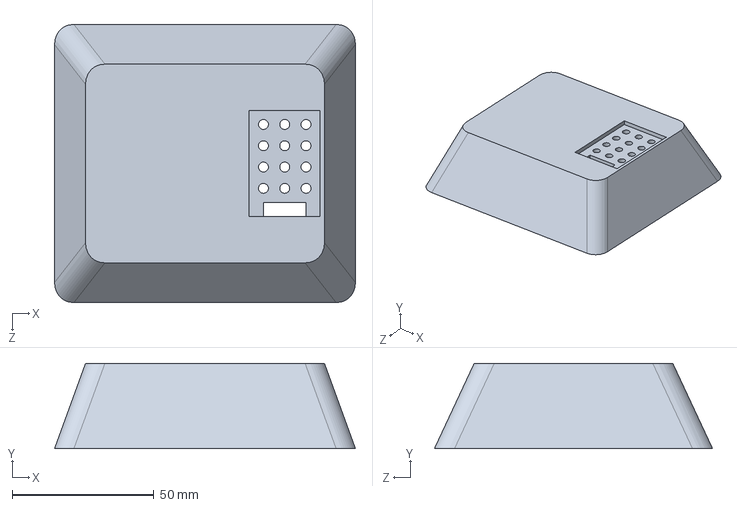
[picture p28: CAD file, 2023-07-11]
hardware/v2/enclosure_top.SLDPRT
106.0 x 30.0 x 98.0 mm

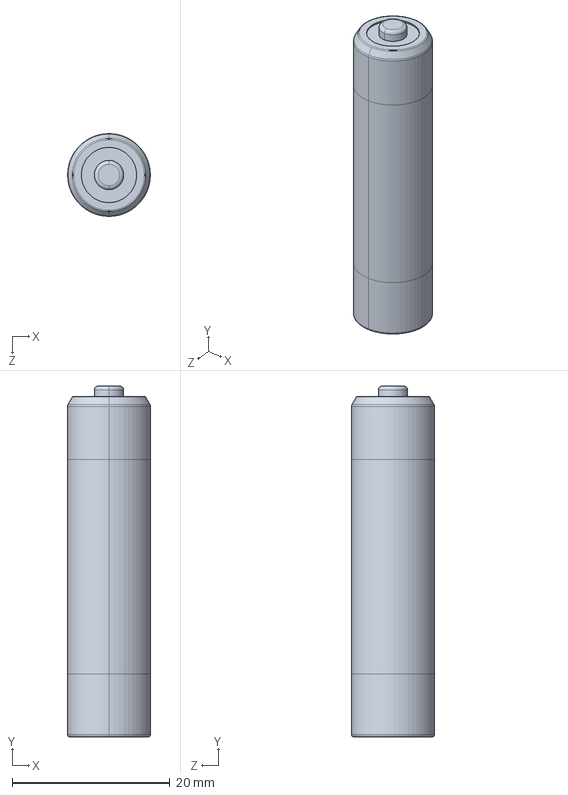
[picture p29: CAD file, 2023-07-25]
pcb/3d_models/BATTERY_AAA_LR03.STEP
10.5 x 44.5 x 10.5 mm

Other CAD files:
hardware/v2/satellite_module.SLDPRT
pcb/3d_models/BATTERY_HOLDER_KS56.STEP
pcb/3d_models/GMCB05801124EU.step
hardware/v2/micro_b_usb_connector.SLDPRT
hardware/v2/battery_AAA.SLDPRT
hardware/v2/microcontroller.SLDPRT
hardware/v2/pcb.SLDPRT
hardware/v1/91287A125_18-8_stainless_steel_hex_head_screw.SLDPRT
hardware/v1/97163A155_tapered_heat_set_insert_for_plastic.SLDPRT
hardware/v1/afridev_C2037_cover_plate.SLDPRT
hardware/v1/enclosure_assembly.SLDASM
hardware/v1/enclosure_bottom.SLDPRT
hardware/v1/enclosure_top.SLDPRT
hardware/v2/91287A125_18-8_stainless_steel_hex_head_screw.SLDPRT
hardware/v2/97163A155_tapered_heat_set_insert_for_plastic.SLDPRT
hardware/v2/battery_terminal_01.SLDPRT
hardware/v2/enclosure_bottom.SLDPRT
pcb/3d_models/BQ25170DSGR.stp
pcb/3d_models/MLX90614ESF-AAA-000-TU.STEP

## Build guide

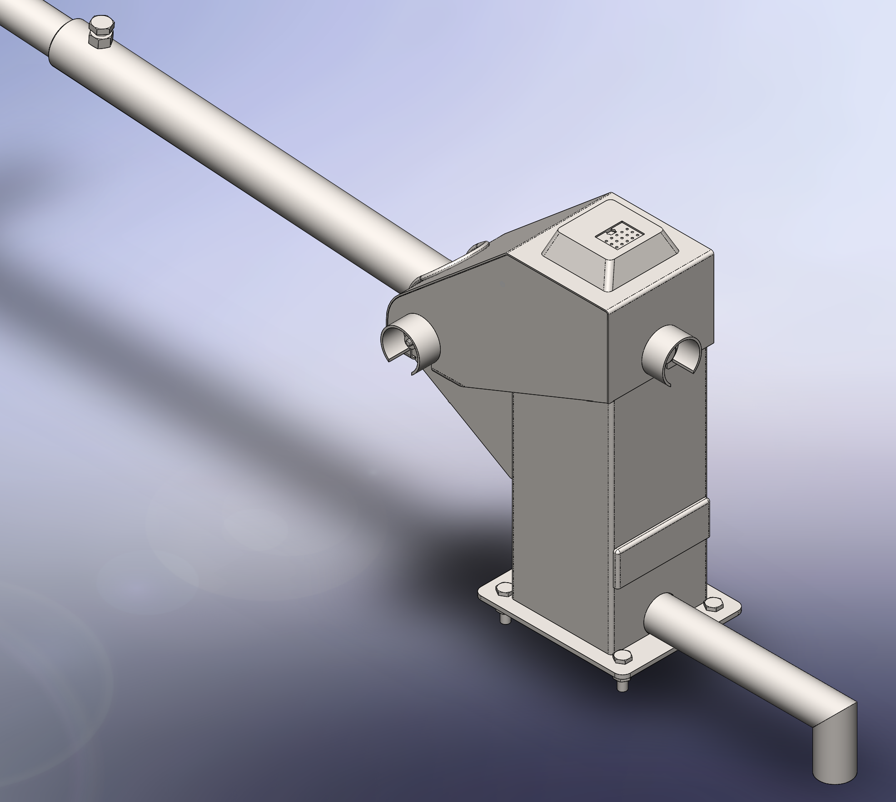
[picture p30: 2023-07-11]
img/v2/assembly_04.png

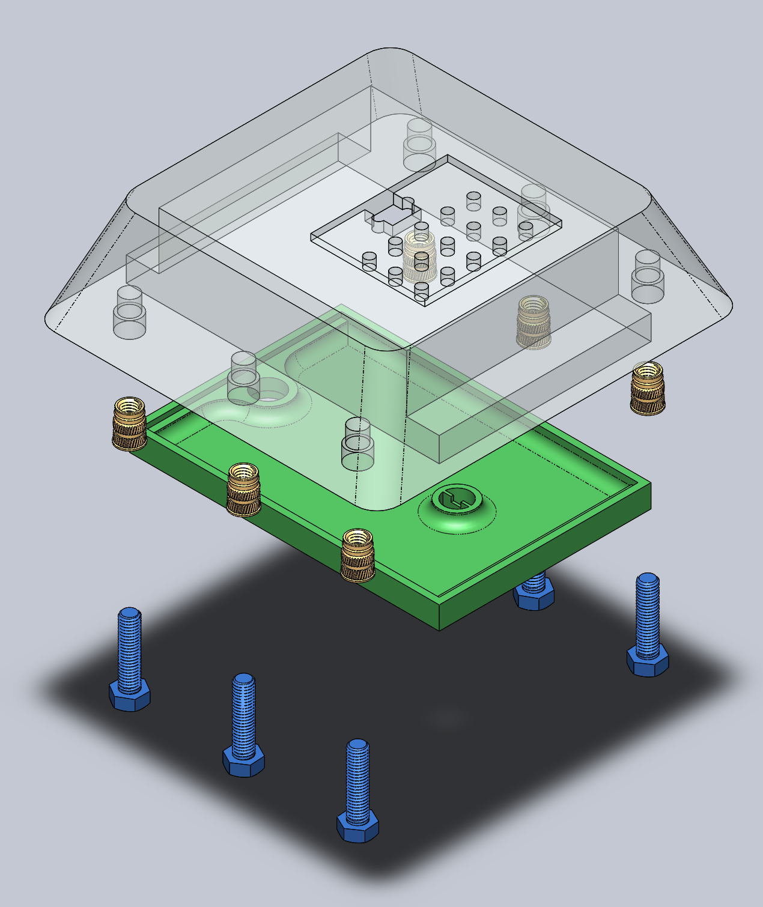
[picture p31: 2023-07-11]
img/v2/assembly_06.png

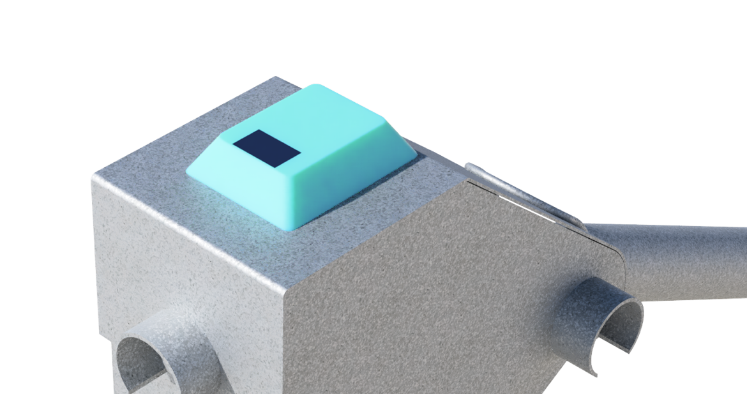
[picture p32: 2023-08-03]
img/assembly_02.png

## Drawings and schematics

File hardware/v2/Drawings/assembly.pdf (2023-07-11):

2

4

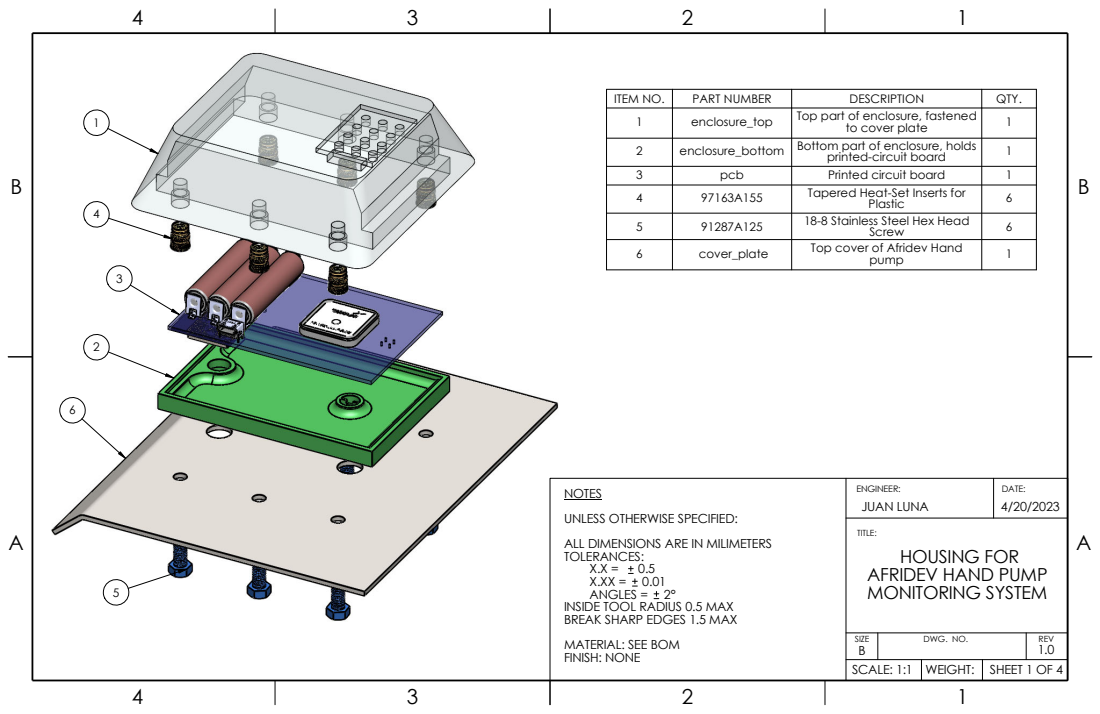
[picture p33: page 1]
ENGINEER:; DATE: 4/20/2023; JUAN LUNA

ITEM NO. | PART NUMBER | DESCRIPTION | QTY.
1 | enclosure_top | Top part of enclosure, fastened to cover plate | 1

2 | enclosure_bottom | Bottom part of enclosure, holds printed-circuit board | 1

3 | pcb | Printed circuit board | 1
4 | 97163A155 | Tapered Heat-Set Inserts for Plastic | 6

5 | 91287A125 | 18-8 Stainless Steel Hex Head Screw | 6
6 | cover_plate | Top cover of Afridev Hand pump | 1

NOTES
UNLESS OTHERWISE SPECIFIED:
ALL DIMENSIONS ARE IN MILIMETERS
TOLERANCES:
ANGLES = 2°
INSIDE TOOL RADIUS 0.5 MAX
BREAK SHARP EDGES 1.5 MAX
MATERIAL: SEE BOM
FINISH: NONE

TITLE:
HOUSING FOR
AFRIDEV HAND PUMP
MONITORING SYSTEM

SIZE B | DWG. NO. | REV 1.0
SCALE: 1:1 | WEIGHT: | SHEET 1 OF 4

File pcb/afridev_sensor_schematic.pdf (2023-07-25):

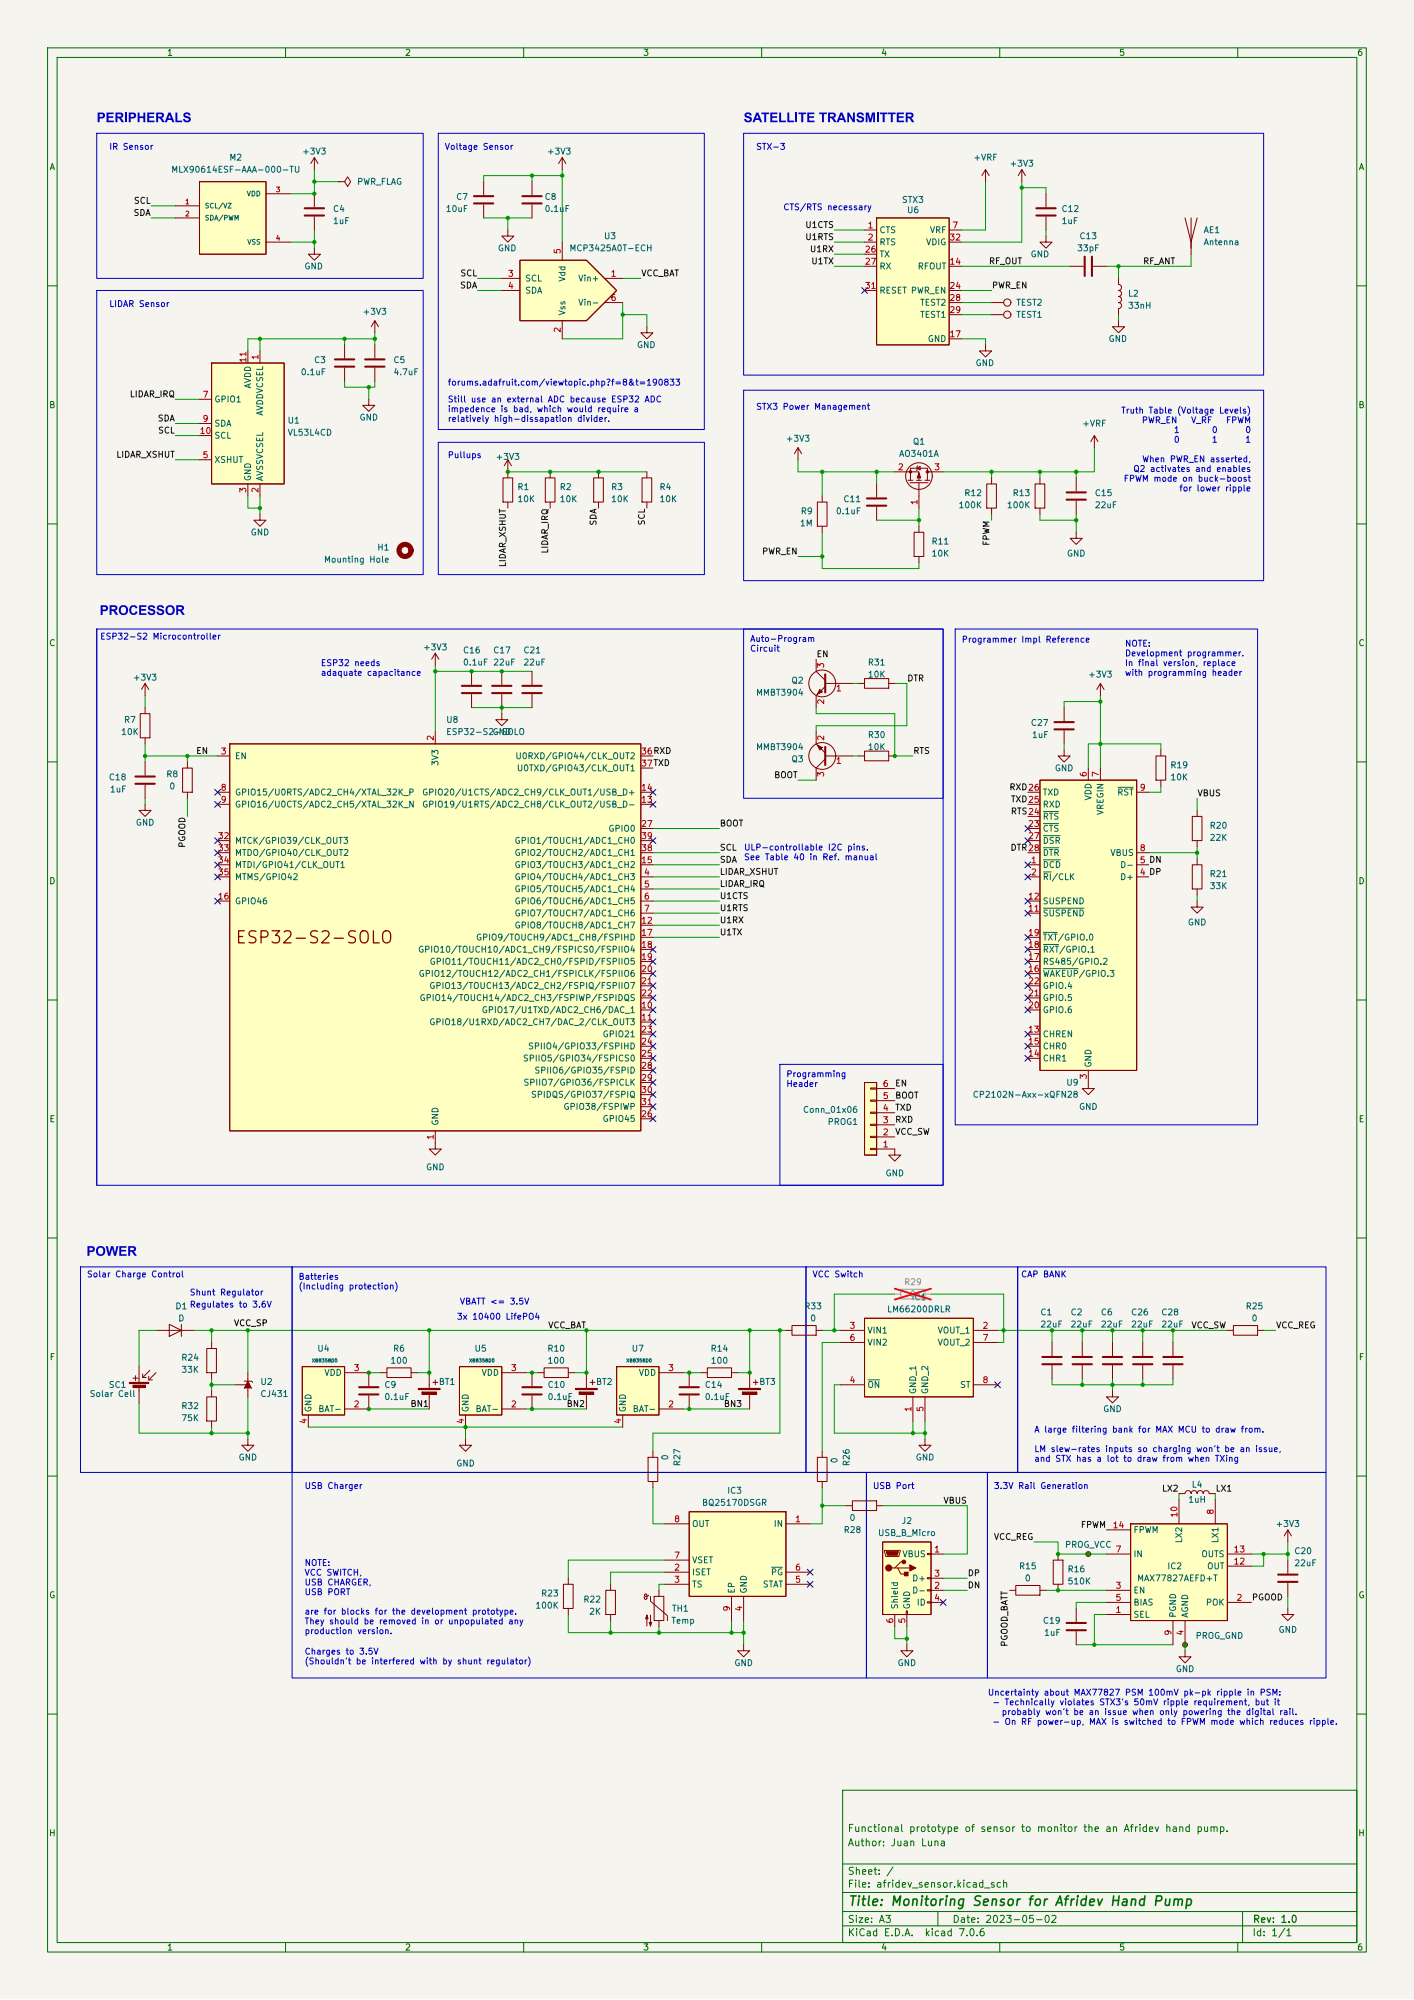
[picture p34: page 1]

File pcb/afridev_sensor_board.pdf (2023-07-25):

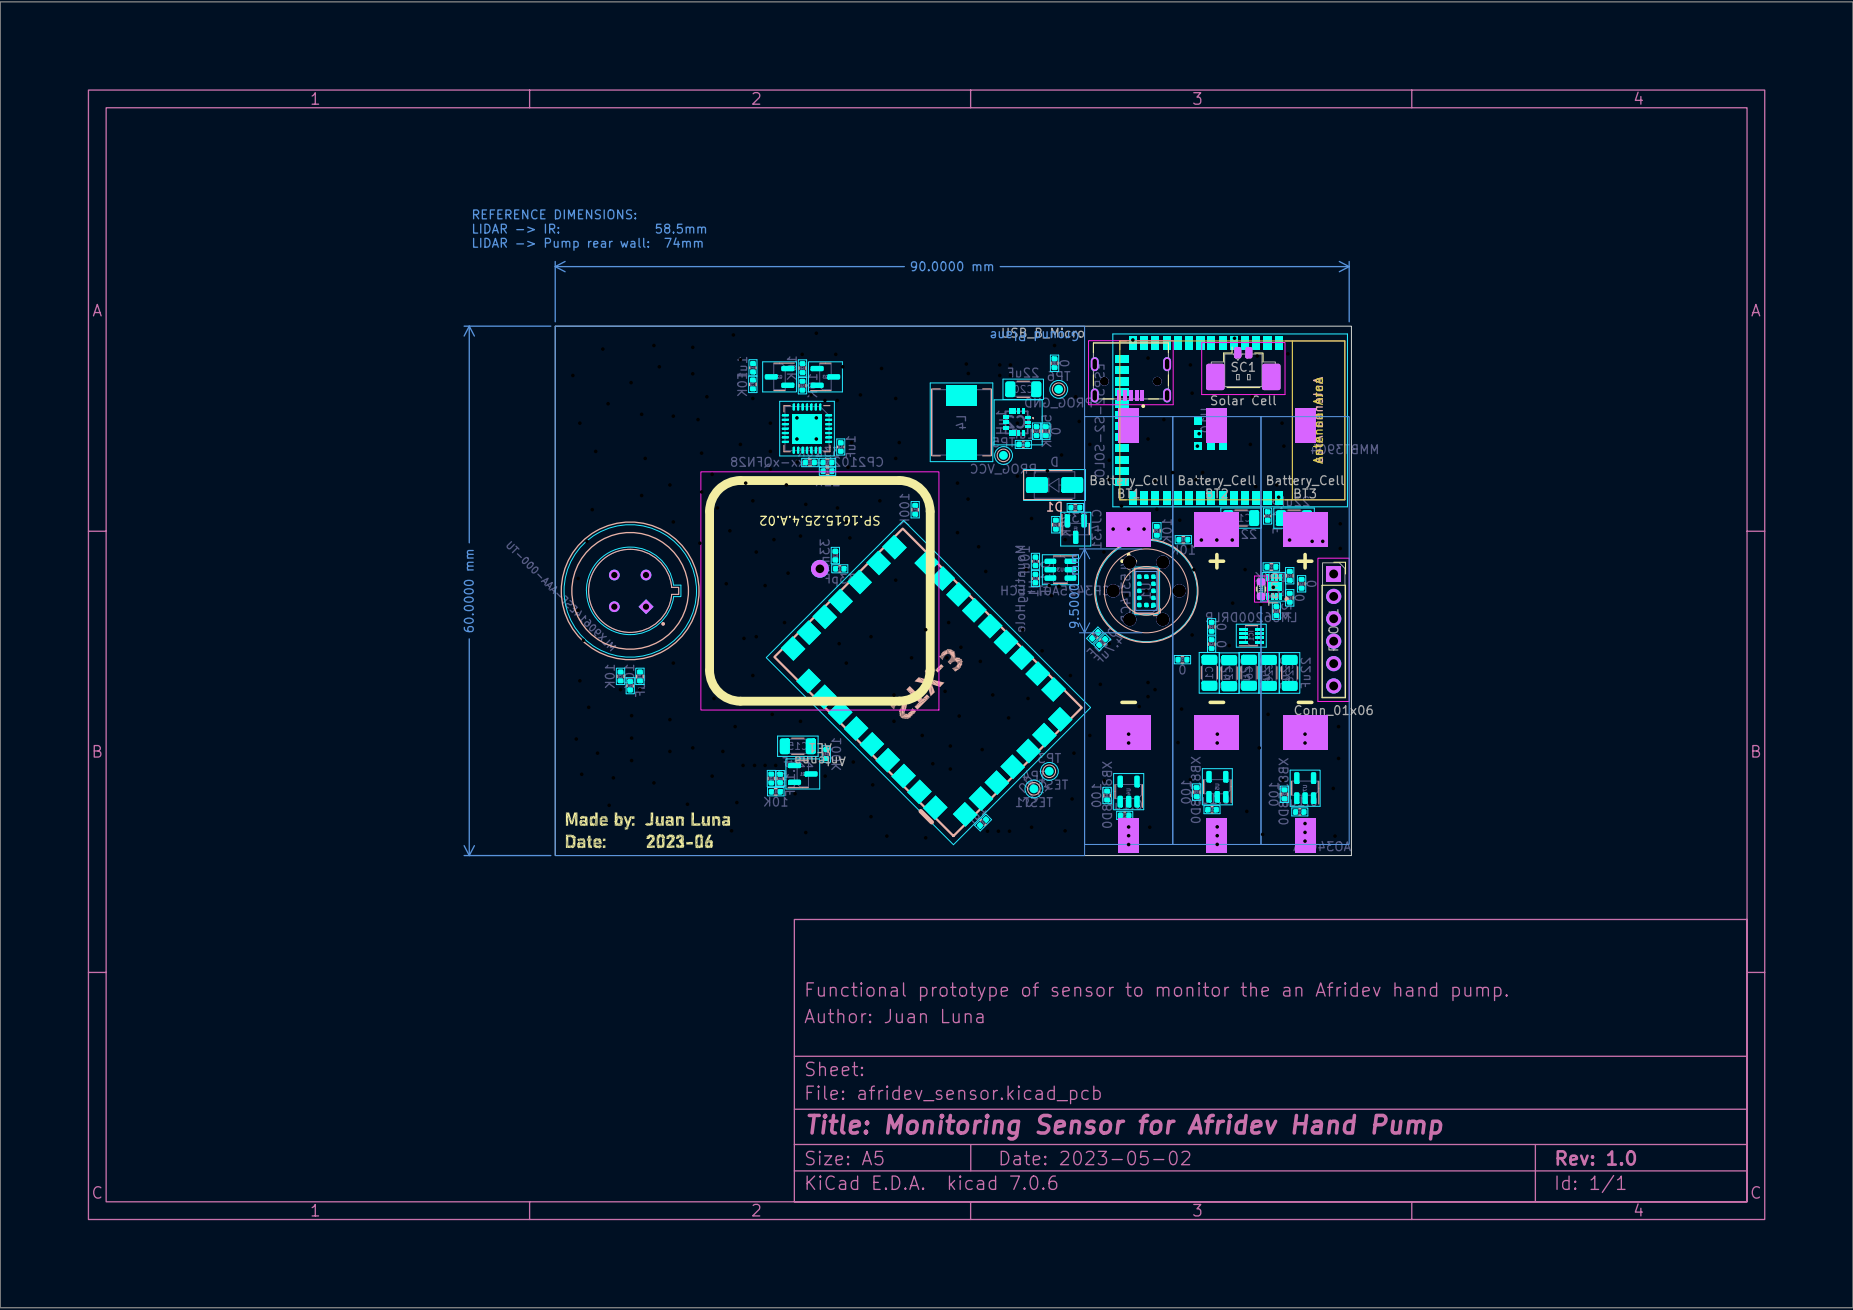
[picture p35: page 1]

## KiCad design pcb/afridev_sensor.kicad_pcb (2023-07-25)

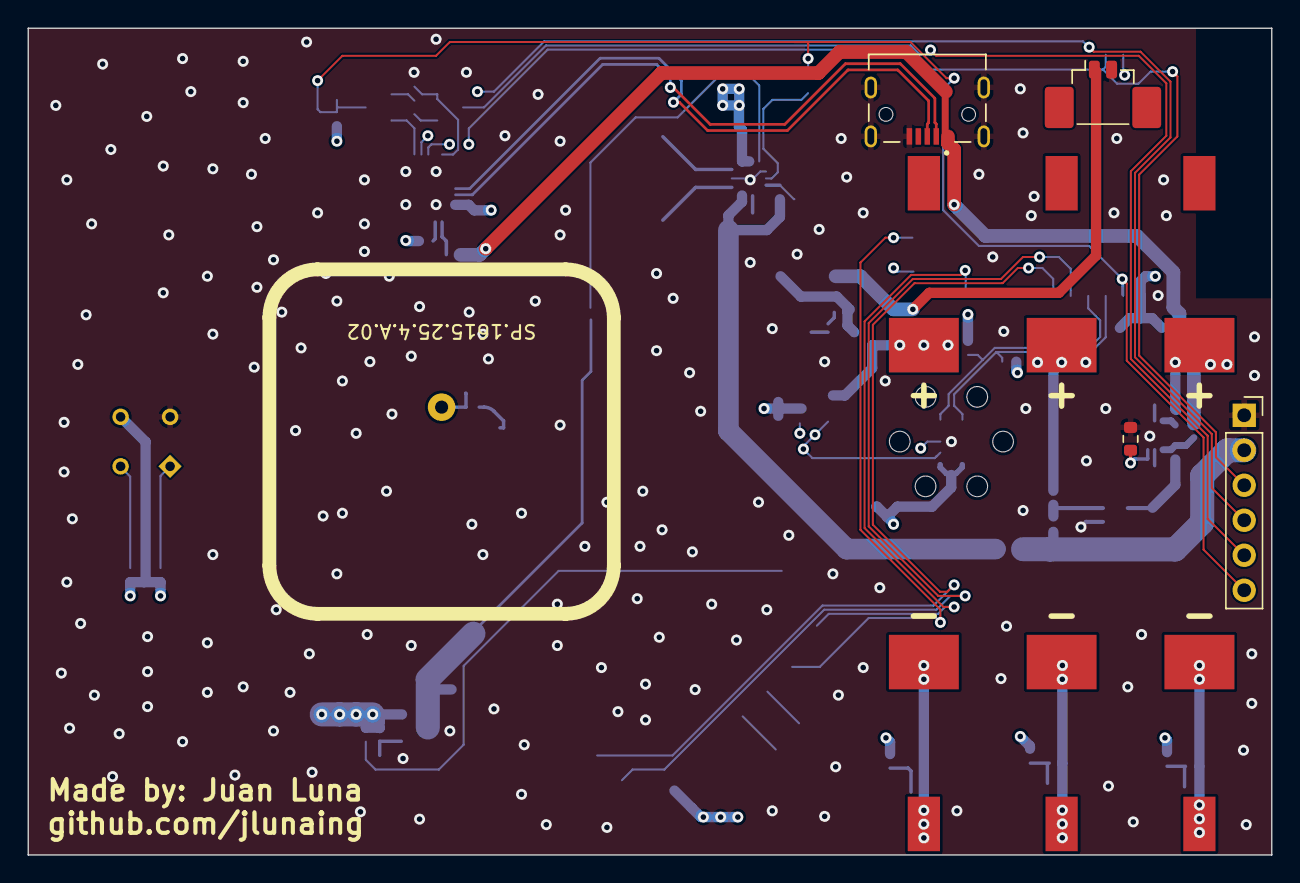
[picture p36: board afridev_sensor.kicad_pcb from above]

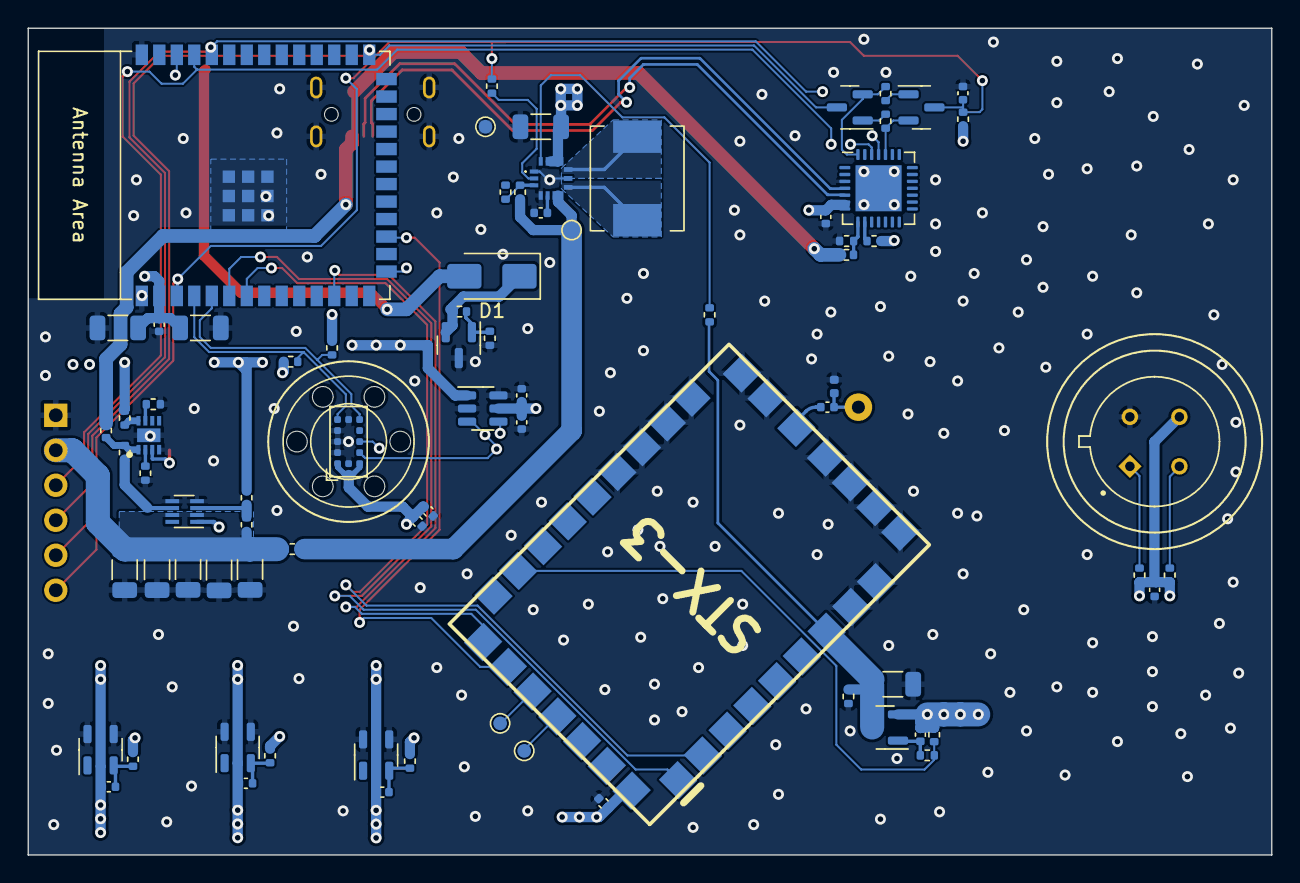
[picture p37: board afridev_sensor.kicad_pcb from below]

Board: 4 copper layers, 90.2 x 60.0 mm, 86 parts (78 on the bottom side), 54 nets.

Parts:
AE1: Antenna; ANT_SP.1615.25.4.A.02
BT1, BT2, BT3: Battery_Cell; Keystone 56
C1, C2, C6, C15, C17, C20, C21, C26, C28: 22uF; C_1206_3216Metric
C3, C8, C9, C10, C11, C14, C16: 0.1uF; C_0402_1005Metric
C4, C12, C18, C19, C27: 1uF; C_0402_1005Metric
C5: 4.7uF; C_0402_1005Metric
C7: 10uF; C_0402_1005Metric
C13: 33pF; C_0402_1005Metric
D1: D; D_SMA
H1: MountingHole; VlVenting
IC1: LM66200DRLR; SC-70-8
IC2: MAX77827AEFD+T; MAX77827AEFD
IC3: BQ25170DSGR; SON50P200X200X80-9N
J2: USB_B_Micro; AMPHENOL_GMCB05801124EU
L2: 33nH; L_0402_1005Metric
L4: 1uH; L_Neosid_SM-PIC0602H
M1: MLX90614ESF-AAA-000-TU; TO254P942H425-4
PROG1: Conn_01x06; PinSocket_1x06_P2.54mm_Vertical
Q1: AO3401A; SOT-23
Q2, Q3: MMBT3904; SOT-23
R1, R2, R3, R4, R7, R11, R19, R30, R31: 10K; R_0402_1005Metric
R6, R10, R14: 100; R_0402_1005Metric
R8, R15, R25, R26, R27, R28, R29, R33: 0; R_0402_1005Metric
R9: 1M; R_0402_1005Metric
R12, R13, R23: 100K; R_0402_1005Metric
R16: 510K; R_0402_1005Metric
R20: 22K; R_0402_1005Metric
R21, R24: 33K; R_0402_1005Metric
R22: 2K; R_0402_1005Metric
R32: 75K; R_0402_1005Metric
SC1: Solar Cell; Molex_PicoBlade_53398-0271_1x02-1MP_P1.25mm_Vertical
TH1: Temp; R_0603_1608Metric
TP3: TEST2; TestPoint_Pad_D1.0mm
TP4: TEST1; TestPoint_Pad_D1.0mm
TP5: PROG_VCC; TestPoint_Pad_D1.0mm
TP6: PROG_GND; TestPoint_Pad_D1.0mm
U1: VL53L4CD; ST_VL53L1x
U2: CJ431; SOT-23
U3: MCP3425A0T-ECH; SOT-23-6
U4, U5, U7: XB8358D0; SOT-23-5
U6: STX3
U9: CP2102N-Axx-xQFN28; QFN-28-1EP_5x5mm_P0.5mm_EP3.35x3.35mm
U10: ESP32-S2-SOLO

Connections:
+3V0: C15.1, Q1.3 (D), R12.1, R13.1, U6.7 (VRF)
+3V3: C3.1, C4.1, C5.1, C7.1, C8.1, C11.1, C12.1, C16.1, C17.1, C20.1, C21.1, C27.1, IC2.12 (OUT), IC2.13 (OUTS), M1.3 (VDD), Q1.2 (S), R1.1, R2.1, R3.1, R4.1, R7.1, R9.1, R19.1, U1.1 (AVDDVCSEL), U1.11 (AVDD), U3.5 (Vdd), U6.32 (VDIG), U9.6 (VDD), U9.7 (VREGIN), U10.2 (3V3)
/BN1: BT1.2 (-), C9.2, U4.2 (BAT-)
/BN2: BT2.2 (-), C10.2, U5.2 (BAT-)
/BN3: BT3.2 (-), C14.2, U7.2 (BAT-)
/BOOT: PROG1.5, Q3.3 (C), U10.27 (GPIO0)
/DN: J2.2 (D-), U9.5 (D-)
/DP: J2.3 (D+), U9.4 (D+)
/DTR: Q3.2 (E), R31.2, U9.28 (~DTR)
/EN: C18.1, PROG1.6, Q2.3 (C), R7.2, R8.1, U10.3 (EN)
/FPWM: IC2.14 (FPWM), R12.2
/LIDAR_IRQ: R2.2, U1.7 (GPIO1), U10.5 (GPIO5/TOUCH5/ADC1_CH4)
/LIDAR_XSHUT: R1.2, U1.5 (XSHUT), U10.4 (GPIO4/TOUCH4/ADC1_CH3)
/LX1: IC2.8 (LX1), L4.2
/LX2: IC2.10 (LX2), L4.1
/PGOOD: IC2.2 (POK), R8.2
/PWR_EN: R9.2, R11.2, U6.24 (PWR_EN)
/RF_ANT: AE1.1 (A), C13.2, L2.1
/RF_OUT: C13.1, U6.14 (RFOUT)
/RTS: Q2.2 (E), R30.2, U9.24 (~RTS)
/RXD: PROG1.3, U9.26 (TXD), U10.36 (U0RXD/GPIO44/CLK_OUT2)
/SCL: M1.1 (SCL/VZ), R4.2, U1.10 (SCL), U3.3 (SCL), U10.38 (GPIO2/TOUCH2/ADC1_CH1)
/SDA: M1.2 (SDA/PWM), R3.2, U1.9 (SDA), U3.4 (SDA), U10.15 (GPIO3/TOUCH3/ADC1_CH2)
/TXD: PROG1.4, U9.25 (RXD), U10.37 (U0TXD/GPIO43/CLK_OUT1)
/U1CTS: U6.1 (CTS), U10.6 (GPIO6/TOUCH6/ADC1_CH5)
/U1RTS: U6.2 (RTS), U10.7 (GPIO7/TOUCH7/ADC1_CH6)
/U1RX: U6.26 (TX), U10.12 (GPIO8/TOUCH8/ADC1_CH7)
/U1TX: U6.27 (RX), U10.17 (GPIO9/TOUCH9/ADC1_CH8/FSPIHD)
/VBUS: J2.1 (VBUS), R20.1, R28.1
/VCC_BAT: BT1.1 (+), BT2.1 (+), BT3.1 (+), D1.1 (K), R6.2, R10.2, R14.2, R24.1, R27.2, R33.1, U2.2 (K), U3.1 (Vin+)
/VCC_REG: IC2.7 (IN), R16.2, R25.2, TP5.1
/VCC_SW: C1.1, C2.1, C6.1, C26.1, C28.1, IC1.2 (VOUT_1), IC1.7 (VOUT_2), PROG1.2, R25.1, R29.2
GND: C1.2, C2.2, C3.2, C4.2, C5.2, C6.2, C7.2, C8.2, C12.2, C15.2, C16.2, C17.2, C18.2, C19.2, C20.2, C21.2, C26.2, C27.2, C28.2, IC1.1 (GND_1), IC1.4 (~ON), IC1.5 (GND_2), IC2.1 (SEL), IC2.4 (AGND), IC2.9 (PGND), IC3.4 (GND), IC3.9 (EP), J2.5 (GND), J2.6 (Shield), L2.2, M1.4 (VSS), PROG1.1, R13.2, R21.2, R22.2, R23.2, R32.2, SC1.2 (-), TH1.2, TP6.1, U1.2 (AVSSVCSEL), U1.3 (GND), U1.4 (GND), U1.6 (GND), U1.12 (GND), U2.3 (A), U3.2 (Vss), U3.6 (Vin-), U4.4 (GND), U4.5 (GND), U5.4 (GND), U5.5 (GND), U6.8 (GND), U6.9 (GND), U6.10 (GND), U6.11 (GND), U6.12 (GND), U6.13 (GND), U6.15 (GND), U6.16 (GND), U6.17 (GND), U6.18 (GND), U6.19 (GND), U6.20 (GND), U7.4 (GND), U7.5 (GND), U9.3 (GND), U9.29 (GND), U10.1 (GND), U10.40 (GND), U10.41 (GND)
unnamed: D1.2 (A), SC1.1 (+)
unnamed: IC1.3 (VIN1), R29.1, R33.2
unnamed: IC1.6 (VIN2), R26.2
unnamed: C19.1, IC2.5 (BIAS)
unnamed: IC2.3 (EN), R15.2, R16.1
unnamed: IC3.1 (IN), R26.1, R28.2
unnamed: IC3.2 (ISET), R22.1
unnamed: IC3.8 (OUT), R27.1
unnamed: IC3.3 (TS), TH1.1
unnamed: IC3.7 (VSET), R23.1
unnamed: C11.2, Q1.1 (G), R11.1
unnamed: Q2.1 (B), R31.1
unnamed: Q3.1 (B), R30.1
unnamed: R24.2, R32.1, U2.1 (REF)
unnamed: C9.1, R6.1, U4.3 (VDD)
unnamed: C10.1, R10.1, U5.3 (VDD)
unnamed: TP4.1, U6.29 (TEST1)
unnamed: TP3.1, U6.28 (TEST2)
unnamed: C14.1, R14.1, U7.3 (VDD)
unnamed: R20.2, R21.1, U9.8 (VBUS)
unnamed: R19.2, U9.9 (~RST)

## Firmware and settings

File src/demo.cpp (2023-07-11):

/** @file   demo.cpp
 *  This file demonstrates the functionality of a monitoring system for the 
 *  Afridev hand pump model. The code estimates volumetric water output using
 *  distance measurements from the VL53L4CX time-of-flight sensor and detects
 *  presence of water using the MLX90614 infrared sensor. The sensor data is 
 *  transmitted through satellite using the STX3 module from GlobalStar.
 * 
 *  @author Juan Luna
 *  @date   2023-Jun-19
 */

#include "demo.h"

// Baud rate for serial communication
#define BAUD 115200
// Pin number for I2C SDA (data) line
#define PIN_SDA 3
// Pin number for I2C SCL (clock) line
#define PIN_SCL 2
// Pin number for VL53L4CD XSHUT (shutdown) line
#define PIN_XSHUT 4
// Pin number for VL53L4CD IRQ (interrupt) line
#define PIN_IRQ 5
// I2C address of MCP3421 ADC (ref 1)
#define MCP_ADDR 0x68

// Timing budget (ms) for VL53L4CD ranging
#define TIMING_BUDGET_MS 100
// Maximum value of ADC reading (10-bit)
#define ADC_MAX 2047
// Adjustment value for negative ADC readings
#define ADC_ADJUST 4095

// MEASUREMENT RANGES
// Distance threshold in millimeters
#define DIST_THRESHOLD 5
// Temperature threshold in degrees Celsius
#define TEMP_THRESHOLD 2

// Maximum water temperature in Celsius
#define MAX_WATER_TEMP 50 // equivalent to 122-F
// Minimum water temperature in Celsius
#define MIN_WATER_TEMP 0  // freezing point
// Maximum distance in millimeters
#define MAX_DIST 450
// Minimum distance in millimeters
#define MIN_DIST 50

// Cross-sectional area of pump in square millimeters
#define PUMP_AREA 1963.5
// Conversion factor from cubic millimeters to liters
#define MMC_TO_L 1000000

// Active state
#define ACTIVE 1
// Inactive state
#define INACTIVE 0

// SENSOR OBJECTS
// VL53L4CD distance sensor using I2C and XSHUT pin
VL53L4CD sensor_vl53l4cd_sat(&Wire, PIN_XSHUT);
// MLX90614 temperature sensor
Adafruit_MLX90614 mlx = Adafruit_MLX90614();

volatile int interruptCount = 0;

float totalVolume_L = 0.0;
int prevDist = 0;
int active = 0;
int maxDist = 0;
int minDist = 10000;

void measure() {
    interruptCount = 1;
}

int read_ext_adc() {
    // Ref 1

    unsigned int data[2];

    // Start I2C Transmission
    Wire.beginTransmission(MCP_ADDR);
    // Select data register
    Wire.write(0x00);
    // Stop I2C Transmission
    Wire.endTransmission();

    // Request 2 bytes of data
    Wire.requestFrom(MCP_ADDR, 2);

    // Read 2 bytes of data
    // raw_adc msb, raw_adc lsb
    if (Wire.available() == 2) {
        data[0] = Wire.read();
        data[1] = Wire.read();
    }

    // Convert the data to 12-bits
    int raw_adc = ((data[0] & 0x0F) << 8) + data[1];
    if (raw_adc > ADC_MAX) {
        raw_adc -= ADC_ADJUST;
    }

    return raw_adc;
}

void setup() {
    // Interrupt
    pinMode(PIN_IRQ, INPUT_PULLUP);
    attachInterrupt(PIN_IRQ, measure, FALLING);

    // Initialize serial for output
    Serial.begin(BAUD);
    Serial << "Starting..." << endl;

    // Initialize I2C bus.
    Wire.begin(PIN_SDA, PIN_SCL);

    // Initialize IR sensor
    if (!mlx.begin(MLX90614_I2CADDR, &Wire)) {
        Serial << "Error connecting to IR sensor. Check wiring." << endl;
        ESP.restart();
    };

    Serial << "Emissivity = " << mlx.readEmissivity() << endl;
    Serial << "================================================";

    // Initialize ADC
    Wire.beginTransmission(MCP_ADDR);
    // Send configuration command
    // Continuous conversion mode, 12-bit resolution
    Wire.write(0x10);
    // Stop I2C Transmission
    Wire.endTransmission();

    // Configure VL53L4CD satellite component.
    sensor_vl53l4cd_sat.begin();
    // Switch off VL53L4CD satellite component.
    sensor_vl53l4cd_sat.VL53L4CD_Off();
    // Initialize VL53L4CD satellite component.
    sensor_vl53l4cd_sat.InitSensor();

    // Program the highest possible TimingBudget, without enabling the
    // low power mode. This should give the best accuracy
    sensor_vl53l4cd_sat.VL53L4CD_SetRangeTiming(TIMING_BUDGET_MS, 0);

    // Start Measurements
    sensor_vl53l4cd_sat.VL53L4CD_StartRanging();

    Serial << "Successfully started." << endl;
}

float getVolume_L(int pumpDist, int active) {
    if (active && ((prevDist - pumpDist) > DIST_THRESHOLD)) {
        return ((prevDist-pumpDist) * PUMP_AREA)/MMC_TO_L;
    }
    else {
        return 0;
    }
}

int statusCheck (int dist, int ambTemp, int objTemp) {
    int deltaDist = dist - prevDist;
    int deltaTemp = objTemp - ambTemp;

    if ((objTemp > MAX_WATER_TEMP) || (objTemp < MIN_WATER_TEMP)) {
        // temperature out of normal range
        return INACTIVE;
    }

    if ((abs(deltaDist) > DIST_THRESHOLD) && (abs(deltaTemp) > TEMP_THRESHOLD)) {
        return ACTIVE;
    }

    return INACTIVE;
}

// The following lines of code are used RealTerm or PuTTY, 
// not PlatformIO serial monitor

// Clear the contents of terminal screen
void clearTerminal(void) {
    Serial.write(27);
    Serial.print("[2J");
    Serial.write(27);
    Serial.print("[H");
}

// Sets the position of the cursor to the beginnig of the line
void newLine(void) {
    Serial.write(27);
    Serial.print("[70D");
}

// Print the information to external terminal
void printInformation(int dist, int adcVol, int ambientTemp, int objectTemp, int active) {

    // Clear the terminal screen
    clearTerminal();
    
    // Print the information
    Serial.printf(" MONITORING SYSTEM DEMO \n");
    newLine();
    Serial.printf("Current Distance: %d mm\n", dist);
    newLine();
    Serial.printf("ADC: %d\n", adcVol);
    newLine();
    Serial.printf("Total Volume Pumped: %f L \n\n", totalVolume_L);
    newLine();
    Serial.printf(" PUMP STATUS \n\n");

    newLine();
    Serial.printf("\t\t");
    if (active) {
        Serial.println("ACTIVE");
    }
    else {
        Serial.println("INACTIVE");
    }
    Serial.printf("\n");
    newLine();
    Serial.printf("******************************************* ");
}

void loop() {
    uint8_t NewDataReady = 0;
    VL53L4CD_Result_t results;
    uint8_t status;
    int active = INACTIVE;

    if (interruptCount) {
        interruptCount = 0;

        status = sensor_vl53l4cd_sat.VL53L4CD_CheckForDataReady(&NewDataReady);

        if ((!status) && (NewDataReady != 0)) {
            // (Mandatory) Clear HW interrupt to restart measurements
            sensor_vl53l4cd_sat.VL53L4CD_ClearInterrupt();

            // Read measured distance. RangeStatus = 0 means valid data
            sensor_vl53l4cd_sat.VL53L4CD_GetResult(&results);

            if((results.distance_mm > MIN_DIST) && (results.distance_mm < MAX_DIST)) {
            // Distance measurement is within expected range
                int adc = read_ext_adc();
                double amb = mlx.readAmbientTempC();
                double obj = mlx.readObjectTempC();

                active = statusCheck(results.distance_mm, amb, obj);
                totalVolume_L += getVolume_L(results.distance_mm, active);
                
                //printInformation(results.distance_mm, adc, amb, obj, active);

                prevDist = results.distance_mm;
                Serial.printf("MEAS:%d,%d,%f,%f, %f,%d\n", results.distance_mm, 
                                        adc, amb, obj, totalVolume_L, active);
            }
        }
    }
}

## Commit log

2023-03-16 Updated circuit schematic with main components
    [afridev_sensor.sch]
2023-04-21 CAD Model of Housing
    First iteration of 3D model of the housing for the electronics.
    [enclosure_assembly.SLDASM, enclosure_bottom.SLDPRT, enclosure_top.SLDPRT]
2023-04-22 Updated CAD model for housing
    [91287A125_18-8_stainless_steel_hex_head_screw.SLDPRT, 97163A155_tapered_heat_set_insert_for_plastic.SLDPRT, afridev_C2037_cover_plate.SLDPRT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]
2023-07-11 Code and CAD update
    Functioning version of demo code and updated CAD files and drawings.
    [91287A125_18-8_stainless_steel_hex_head_screw.SLDPRT, 97163A155_tapered_heat_set_insert_for_plastic.SLDPRT, ESP32-WROOM-32E.SLDASM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]
2023-07-25 Update with schematic and board files
    [BATTERY_AAA_LR03.STEP, BATTERY_HOLDER_KS56.STEP, BQ25170DSGR.stp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]
